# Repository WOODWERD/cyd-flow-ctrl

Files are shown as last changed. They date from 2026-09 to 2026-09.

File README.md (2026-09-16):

# Flow Ctrl — a push-to-talk button for Wispr Flow on the Cheap Yellow Display

_An open-hardware project from [WOODWERD LLC](https://woodwerd.com), a design group in Austin, Texas._

A dedicated desk button for [Wispr Flow](https://wisprflow.ai) dictation, built on the
ESP32-2432S028R "Cheap Yellow Display" (CYD). The board pairs with your Mac as a **Bluetooth
keyboard** and sends the same keyboard shortcut you already use — so there is nothing to install on
the computer, and nothing about your Wispr setup changes.

- **Hold to talk** — press and hold the big button, speak, let go: Wispr transcribes and pastes.
- **Hands-free** — tap once to lock in, talk for as long as you like, tap **STOP** to paste it all.
- **Send** — a Return key, so a dictated Claude prompt or chat message goes without touching the keyboard.
- **Discard** — sends `Esc` to throw the dictation away.
- **Transforms** — a second page fires Wispr's AI rewrites (Prompt Engineer, plus your own) on selected text.
- Printed split case with only USB-C exposed. STL/STEP included.

**New here?** [Build it](docs/BUILD.md) (parts, printing, inserts, assembly) then the [Getting Started guide](docs/GETTING_STARTED.md) (setup and every button, with annotated screens).

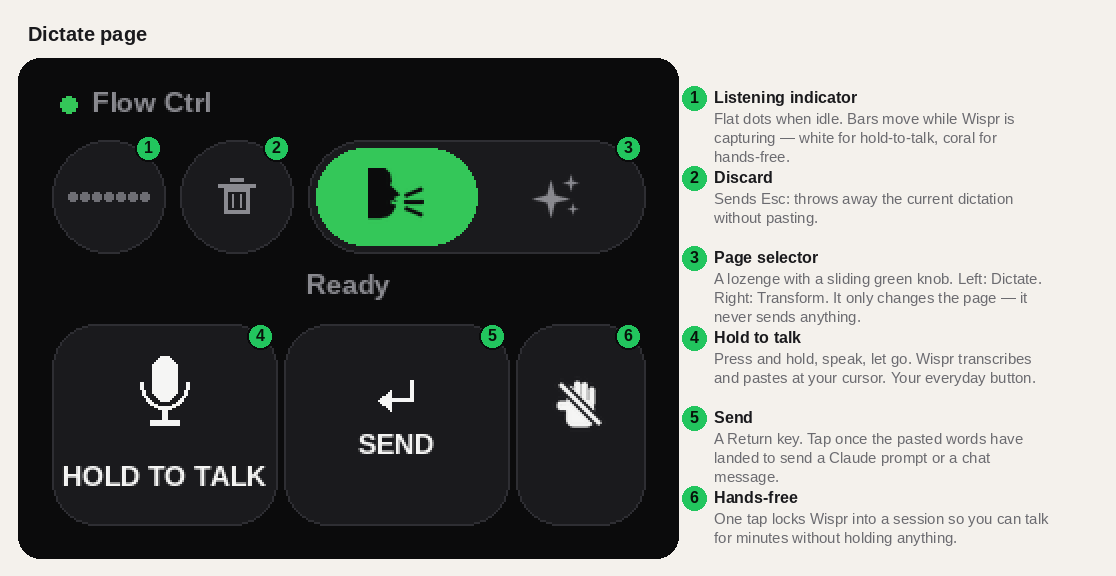
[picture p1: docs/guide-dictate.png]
Dictate page

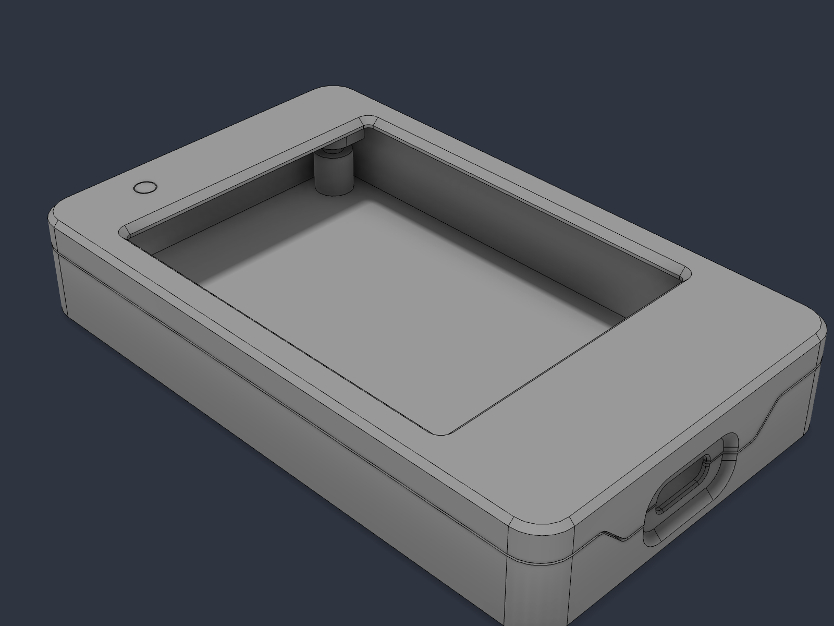
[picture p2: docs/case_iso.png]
Case


> Unofficial. Not affiliated with or endorsed by Wispr. See [THIRD_PARTY_NOTICES.md](THIRD_PARTY_NOTICES.md).

## How it works

Wispr Flow's push-to-talk is a keyboard shortcut. A MacBook's `Fn` key is not a real keycode, so no
external device can send it — but any chord with a normal modifier can be sent by a Bluetooth HID
keyboard, which is what the ESP32 pretends to be. The firmware ships with **Ctrl + Opt + T**; set
Wispr's *Push to talk* shortcut to that (Settings → General → Shortcuts), or rebuild with your own chord.

| On the screen | What the CYD sends | What Wispr does |
|---|---|---|
| **HOLD TO TALK** (press and hold) | chord held down for as long as your finger is | push-to-talk; release = transcribe & paste |
| **HANDS-FREE** (slashed-hand key, tap) | chord tapped twice, 120 ms apart | Wispr's "double-tap push-to-talk to lock" gesture → hands-free session |
| **STOP** (tap, while hands-free) | chord tapped once | ends the session, pastes |
| **STOP** (long-press) | nothing | resets the button's state only — use if you stopped Flow from the Mac |
| **SEND** | `Return` | sends what was just pasted — a Claude prompt, a chat message. Tap it once the words have landed |
| **Discard** (trash button in the top row) | `Esc` | discards the current dictation |
| **Page selector** (lozenge, top row) | nothing | slides between the Dictate and Transform pages |

There is no channel from Wispr back to the button, so the on-screen state is the button's best
guess. If they get out of sync, long-press STOP.

## Quick start (no toolchain)

1. **Flash.** Grab `release/flow-ctrl-v0.9.3-cyd2usb.bin` (USB-C / 2-USB board) or build the `cyd` env
   for the original micro-USB board. Either:
   - [ESP Web Tools / esptool-js](https://espressif.github.io/esptool-js/) in Chrome or Edge — 460800 baud, address `0x0`, or
   - `pip install esptool` then
     ```
     esptool.py --chip esp32 --port /dev/cu.usbserial-XXXX --baud 460800 write_flash 0x0 flow-ctrl-v0.9.3-cyd2usb.bin
     ```
   (Hold BOOT while plugging in if the port doesn't show up. 921600 baud is unreliable on the CH340.)
2. **Pair.** System Settings → Bluetooth → **"Flow Ctrl"**. The top-left dot turns green and the buttons
   enable. The bond is remembered and reconnects on power-up.
3. **Wispr Flow.** Settings → General → Shortcuts → *Push to talk* → press `Ctrl + Opt + T`.
   Wispr's hands-free lock follows the push-to-talk key automatically, so that's the only setting.
4. Talk.

If the chords do nothing in Terminal or a password field, that's macOS *Secure Keyboard Entry* — see
Wispr's help article on it. It affects every keyboard, not just this one.

## Page 2 — Transforms

The lozenge selector in the top row (talking head = Dictate, sparkles = Transform; a green knob slides to the active one) flips to a second page that fires Wispr's *Transforms* — AI rewrites
of whatever text is selected on the Mac. Buttons come from the `XFORMS` table at the top of `main.cpp`;
add a row, rebuild, and it appears in the next empty slot (four slots per page).

| Button | Sends | Set up in Wispr → Settings → Transforms |
|---|---|---|
| **PROMPT ENGINEER** | `Opt+2` | built in |
| **DRAWING NOTE** | `Opt+3` | custom: *Rewrite as terse construction-drawing callouts: material, size, finish, location. Fragments, not sentences. Uppercase. Keep dimensions exact.* |
| **CLIENT EMAIL** | `Opt+4` | custom: *Rewrite as a warm, concise client email from a residential designer. Plain language, no jargon. Keep every decision, dimension, price and date exact. End with one clear next step.* |
| **Select all** | `Cmd+A` | — |
| **View diff** | `Opt+O` | built in |

The Claude flow: dictate into the prompt box → **Select all** → **PROMPT ENGINEER** → back to **DICTATE** → **SEND**.
The top row — waveform circle, trash (Esc) and the page selector — is shared by both pages, so you can see a hands-free session running and discard it from either page. Switching is a tap, not a swipe, so a heavy finger on HOLD TO TALK can never turn into a page change.

## Docs

- [Build it](docs/BUILD.md) — bill of materials, which board to buy, printing, heat-set inserts, screws, assembly
- [Flash it](docs/flash/index.md) — one-click install from Chrome (on the docs site), or esptool
- [Getting Started](docs/GETTING_STARTED.md) — setup, every button and its intent, the three flows, troubleshooting
- [Case](case/README.md) — the printable files, print settings, tolerances
- [Firmware & code](docs/firmware.md) — build flags, code map, how to drive another app with it
- [Changelog](CHANGELOG.md)
- [Publishing checklist](docs/PUBLISHING.md) — how this reaches the CYD project list and the docs site

## Case

See [`case/README.md`](case/README.md): three parts, no supports, PETG, four M3 × 14 countersunk
screws and four M3 × 4 mm heat-set inserts. Only the USB-C port is exposed; a clear light pipe
carries the ambient-light sensor through the lid.

## License

Firmware, case and documentation: © 2026 WOODWERD LLC, released under MIT (see `LICENSE`). Third-party components and fonts retain their
own licences — listed in `THIRD_PARTY_NOTICES.md`.

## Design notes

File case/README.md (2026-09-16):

# Case — split PETG housing for the CYD (USB-C variant)

Three printed parts, four screws, four inserts. The step-by-step build (buying the board, inserts, assembly, with pictures) is in [`../docs/BUILD.md`](../docs/BUILD.md); the parts list as a spreadsheet is [`BOM.csv`](BOM.csv). Only the USB-C port is exposed; the light sensor gets a
clear light pipe so the firmware's ambient-light features still work behind a closed lid. Designed in
Fusion 360 by WOODWERD LLC; STL for printing, STEP if you want to modify it. This is housing **v2** — printed, test-fitted on a USB-C board, and the released design.

Case

| File | Part | Qty | Print |
|---|---|---|---|
| `CYD_FlowCtrl_Base.stl` | Base — board drops in USB-C end first, screws from below | 1 | open side **up**, no supports |
| `CYD_FlowCtrl_Lid.stl` | Lid — display window, insert bosses, USB-C tongue | 1 | face **down** on the bed, no supports |
| `CYD_FlowCtrl_LightPipe.stl` | Light pipe for the LDR — Ø2.9 rod on a Ø5 flange | 1 | **clear** filament, flange down, 100 % infill |

Outer size 54.6 × 90.6 × 16.1 mm. Wall 2.0 mm, 0.3 mm clearance per side around the board. Volumes:
base 15.2 cm³, lid 5.4 cm³.

## Print settings that matter
- **Material:** PETG recommended (heat-set inserts seat cleanly; PLA works at a lower iron temperature).
- **Layer height:** 0.2 mm (0.16 for a nicer display chamfer). 3–4 perimeters so the lip and groove are solid.
- **No supports** on any part. The USB-C funnel is a 45° loft and the port hole is bridged by the tongue.
- **Tolerances:** the lid rides on a 0.9 mm lip with 0.15 mm lateral clearance and a designed 0.3 mm
  parting-line gap outside. If your printer runs fat, a −0.1 mm horizontal expansion (XY compensation)
  on the lid is the first thing to try. If a USB-C cable won't click home, the local wall at the port
  is 0.8 mm — sand the lead-in chamfer before reprinting.
- **Test print first:** the base alone, and try a cable in it. That's the only fit that matters.

## Hardware (BOM)
| Qty | Part | Spec |
|---|---|---|
| 4 | M3 × 14 mm flat-head screw, 90° countersunk, hex socket | DIN 7991 / ISO 10642. Not M3 × 16 — the tip would reach the lid face. |
| 4 | M3 brass heat-set insert, **4 mm long**, OD 4.0–4.2 | The "M3 × L4" kit size (Voron M3×5×4 also fits). 5.7 mm inserts bottom out. |
| 1 | Cheap Yellow Display **USB-C / 2-USB** variant (ESP32-2432S028R with Type-C) | The micro-USB-only board also fits mechanically but its port is covered. |

Full fastener sheet with a section drawing: [`Fastener_Spec.pdf`](Fastener_Spec.pdf).

## Assembly
1. Heat-set the four inserts into the lid bosses — soldering iron with an M3 insert tip, ~230 °C for PETG
   (~200 °C for PLA), press to flush, let cool. Do this **before** the board goes in.
2. Push the light pipe up into its tube on the lid ceiling from inside, flange against the ceiling.
3. Flash the board first (it's easier with it out of the case), then drop it into the base, USB-C end first.
4. Lid on: tongue into the slot over the port, lip into the groove. Four screws from below, snug only — it's plastic.

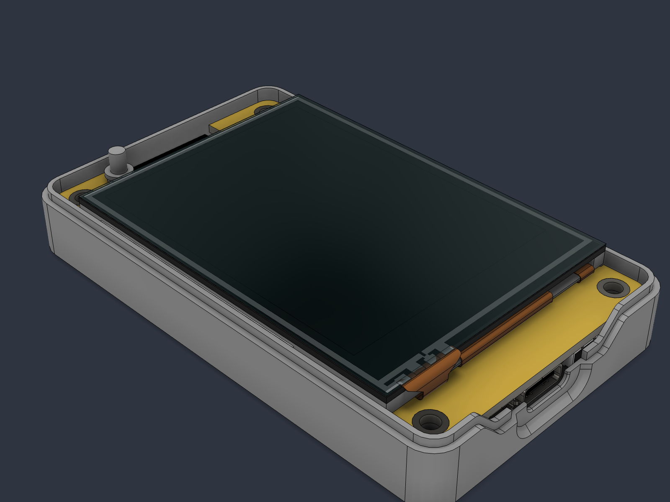
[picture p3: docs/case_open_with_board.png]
Board in base

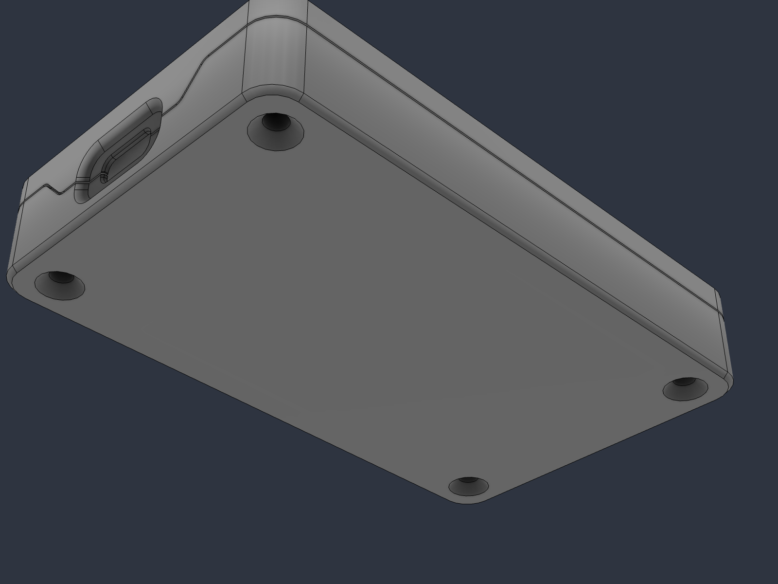
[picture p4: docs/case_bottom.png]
Underside


## What's covered / open
- Exposed: USB-C, light sensor (via pipe), display, touch.
- Covered: micro-USB, microSD, RST/BOOT buttons, JST headers, RGB LED (it may show through light-coloured filament).
  A flip-down SD door is the obvious next feature if you need the card slot.

## Modifying
`*.step` files are exact geometry. All corner radii are concentric with the board's R2.5 corners
(centres at ±22.5, ±40.5 mm from the board centre); the split is at z 2.5 mm above the PCB underside.

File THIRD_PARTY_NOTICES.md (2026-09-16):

# Third-party notices

Flow Ctrl itself is © 2026 WOODWERD LLC, MIT-licensed (see `LICENSE`). It is built on, and distributes, the following.

## Compiled into the firmware (`release/*.bin` and the PlatformIO build)

| Component | License | Notes |
|---|---|---|
| [LVGL](https://github.com/lvgl/lvgl) 9.5 | MIT | UI toolkit. `include/lv_conf.h` is derived from LVGL's template. |
| [TFT_eSPI](https://github.com/Bodmer/TFT_eSPI) | FreeBSD (BSD-2) + portions BSD from Adafruit_GFX | Display driver |
| [XPT2046_Touchscreen](https://github.com/PaulStoffregen/XPT2046_Touchscreen) | MIT | Touch controller |
| [NimBLE-Arduino](https://github.com/h2zero/NimBLE-Arduino) 2.x | Apache-2.0 (Apache NimBLE) | Bluetooth LE HID |
| [arduino-esp32](https://github.com/espressif/arduino-esp32) core | LGPL-2.1 | Arduino core for ESP32. Full source of this project is provided, satisfying relinking requirements. |
| [ESP-IDF](https://github.com/espressif/esp-idf) components (bundled by the platform) | Apache-2.0 | |
| [platform-espressif32](https://github.com/platformio/platform-espressif32) | Apache-2.0 | Build platform only; not distributed |

The BLE HID report map in `src/ble_kbd.cpp` follows the USB HID boot-keyboard layout published in the
USB HID Usage Tables (a public specification). The PnP ID values are the community-conventional ones
used by ESP32 BLE keyboard projects and do not claim a registered vendor ID.

## Fonts (`src/assets/*.c`, converted with `lv_font_conv`)

| Font | License | File |
|---|---|---|
| [Inter](https://github.com/rsms/inter) SemiBold 14/16/20 px | SIL Open Font License 1.1 | `src/assets/LICENSE-Inter-OFL.txt` |
| [IBM Plex Mono](https://github.com/IBM/plex) Medium 14 px | SIL Open Font License 1.1 | `src/assets/LICENSE-IBMPlex-OFL.txt` |

The `.c` files are bitmap conversions of subsets of these fonts, embedded in the firmware. Under the
OFL they are Modified Versions: they remain under the OFL, are not sold on their own, and the file
names use the original names only to identify their origin.

The UI icons (`src/assets/ic_*.c`, drawn by `tools/make_icons.py`) are original and MIT like the rest of the project.

## Hardware and CAD references

- The case was designed around the CYD board CAD model published in
  [witnessmenow/ESP32-Cheap-Yellow-Display](https://github.com/witnessmenow/ESP32-Cheap-Yellow-Display)
  (`3dModels/Havenview_CYD_CAD`), which is MIT-licensed. That model is **not** redistributed here —
  only the case bodies designed for it. Board pin assignments come from the same repository's `PINS.md`.
- USB-C opening dimensions follow the public USB Type-C Cable and Connector Specification, Appendix B.
- "Cheap Yellow Display" / CYD is a community nickname for the Sunton ESP32-2432S028 board; no Sunton
  documentation is redistributed.

## Trademarks

**Wispr Flow** is a trademark of Wispr AI, Inc. This project is an independent, unofficial accessory
that emulates a Bluetooth keyboard and sends ordinary keyboard shortcuts to the Wispr Flow app. It is
not affiliated with, endorsed by, or supported by Wispr. No Wispr artwork, logos, or code are used;
the on-screen waveform pill is an original drawing inspired by the app's listening indicator.
"Flow Ctrl" is used descriptively (a key that triggers Flow) and is not claimed as a brand.

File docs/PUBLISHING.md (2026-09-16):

# Publishing checklist

_Status: firmware v0.9.3 in daily use (v0.9 + the Bluetooth link fix); housing v2 printed, test-fitted and released as-is. Any later housing change: re-export `case/*.stl|step` and the renders from Fusion, rerun `tools/make_guide.py`, push._

This folder is a ready-to-push GitHub repository. Steps, in order.

## 1. The repo and the docs site
- Repo: **https://github.com/WOODWERD/cyd-flow-ctrl** (public; created 2026-09-16).
- Docs site: **https://woodwerd.github.io/cyd-flow-ctrl/** — built from `docs/` by `.github/workflows/pages.yml`
  (MkDocs Material) on every push to `main`. The workflow reuses the README as the home page, `case/README.md`
  as "The case" and the notices file, so there is one copy of every document. `docs/flash/` is an ESP Web Tools
  page that flashes `release/*.bin` from Chrome in one click.
- Settings → Pages → Source is **GitHub Actions** (set by hand 2026-09-16 — GitHub only allows it once the repo
  has content, and the workflow token can't set it).
- Day to day: edit, commit and push with GitHub Desktop (the folder is added there) or
  `git push` from a terminal. Each push rebuilds the site in about a minute; check the Actions tab if it doesn't.

Repo description: *Push-to-talk / hands-free button for Wispr Flow on the ESP32 Cheap Yellow Display, with a printed case.*
Topics worth adding: `esp32`, `cheap-yellow-display`, `cyd`, `wispr-flow`, `ble-hid`, `lvgl`, `3d-printing`.

## 2. Make a release
Tag the version (currently `v0.9.3`) and attach `release/flow-ctrl-v0.9.3-cyd2usb.bin` (and a `cyd` build if you make one) so people
can flash without cloning. Keep the file in `release/` too — the README links to it.

## 3. Add it to the CYD project list
The CYD repo lists community projects in `PROJECTS.md` and asks that you add your own by PR at the
bottom of the table (open source + functional are the only requirements). Fork
`witnessmenow/ESP32-Cheap-Yellow-Display`, append this row, open the PR:

```
| Flow Ctrl | Push-to-talk / hands-free button for Wispr Flow dictation — the CYD pairs as a Bluetooth keyboard; includes a printed case | WOODWERD LLC | None | [Github](https://github.com/WOODWERD/cyd-flow-ctrl) | |
```

Adjust the column order to whatever the table has when you get there (Name · Description · Author ·
Additional Hardware? · Project Page · WebFlash). The case can also be offered as a line under
"Other cases from elsewhere" in `3dModels/README.md` pointing at `case/`, if you'd like it findable
from there too — that list already links out to Printables/MakerWorld/GitHub.

## 4. Optional: web flasher
The CYD list has a WebFlash column. A GitHub Pages site with ESP Web Tools and a `manifest.json`
pointing at the merged bin is an afternoon's work and lets people flash from Chrome with one click;
the Feeder-panel-style `esptool-js` route works but needs the user to type the address.

## 5. Optional: Printables / MakerWorld
Upload `case/*.stl` with the three renders in `docs/` and the text of `case/README.md`. Link back to
the repo for firmware. License choice there: CC-BY-4.0 is the usual pick for models (MIT is fine
too; just be consistent with the repo).

## Before pushing — things checked already
- No personal paths, serial-port names, or unrelated project references in the tree.
- Getting Started / Build guides and their images regenerate from `tools/make_guide.py` — rerun after any screen change so the pictures match the firmware.
- Fonts carry their OFL licence files; third-party libraries listed with licences.
- Wispr trademark disclaimer present; no Wispr artwork or code included.
- CYD board CAD (MIT) is referenced, not redistributed.
- BLE manufacturer string is "WOODWERD LLC", matching the LICENSE and README attribution.

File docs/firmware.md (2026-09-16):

# Firmware & code

## Build it yourself

```
pip install platformio
pio run -e cyd2usb          # USB-C / 2-USB board (ST7789, BGR)
pio run -e cyd              # original micro-USB board (ILI9341)
tools/merge.sh cyd2usb v0.9.3 # single 0x0 image from the build
```

Build flags (add to `build_flags` or `-D` on the command line):

| Flag | Default | Meaning |
|---|---|---|
| `PTT_MODS` | `(MOD_CTRL\|MOD_OPT)` | modifier bits of your Wispr push-to-talk chord (`MOD_CTRL`, `MOD_SHIFT`, `MOD_OPT`, `MOD_CMD`) |
| `PTT_KEY` | `KEY_T` | the key in the chord (`KEY_T`, `KEY_SPACE`, or any HID usage code) |
| `PANEL_ROTATION` | `1` | `3` flips the landscape image 180° (USB on the other side) |
| `BLE_NAME` | `"Flow Ctrl"` | name shown in Bluetooth settings |
| `DIM_AFTER_MS` | `0` | `0` = always full brightness (the board is USB-powered). Set e.g. `45000` to dim after idle; it never turns off |
| `LED_QUIET` | unset | define to silence the RGB LED |
| `TOUCH_DEBUG` | unset | print raw touch coordinates on serial |

Stack: PlatformIO · espressif32 7.1.3 (Arduino) · LVGL 9.5 · TFT_eSPI · XPT2046_Touchscreen ·
NimBLE-Arduino 2.x. ~103 KB RAM, ~890 KB flash. Compiles clean with no PSRAM.

## The screen

Landscape 320 × 240. The visual cue is Wispr's own listening indicator: a dark circle with a row of
bars that lie flat as dots when idle and breathe while you're talking — white for push-to-talk,
coral when locked into hands-free. The rim of the circle and the RGB LED follow the same state.
Buttons are big because you'll hit them without looking: HOLD TO TALK and SEND are equal at 112 × 100 px,
with a 64 px hands-free key (a slashed-hand icon) on the right. Start hands-free and the row re-flows —
HOLD TO TALK slides off, SEND slides left, and a big coral STOP fills the rest until you tap it. The backlight stays at full brightness — the board is USB-powered,
so there is nothing to save and never a "wake-up" tap.

Colours, radii and fonts are tokens in `src/theme.h`. `tools/mock.py` renders every state with PIL so
you can retune without flashing; `tools/make_guide.py` builds the annotated screens in `docs/`.

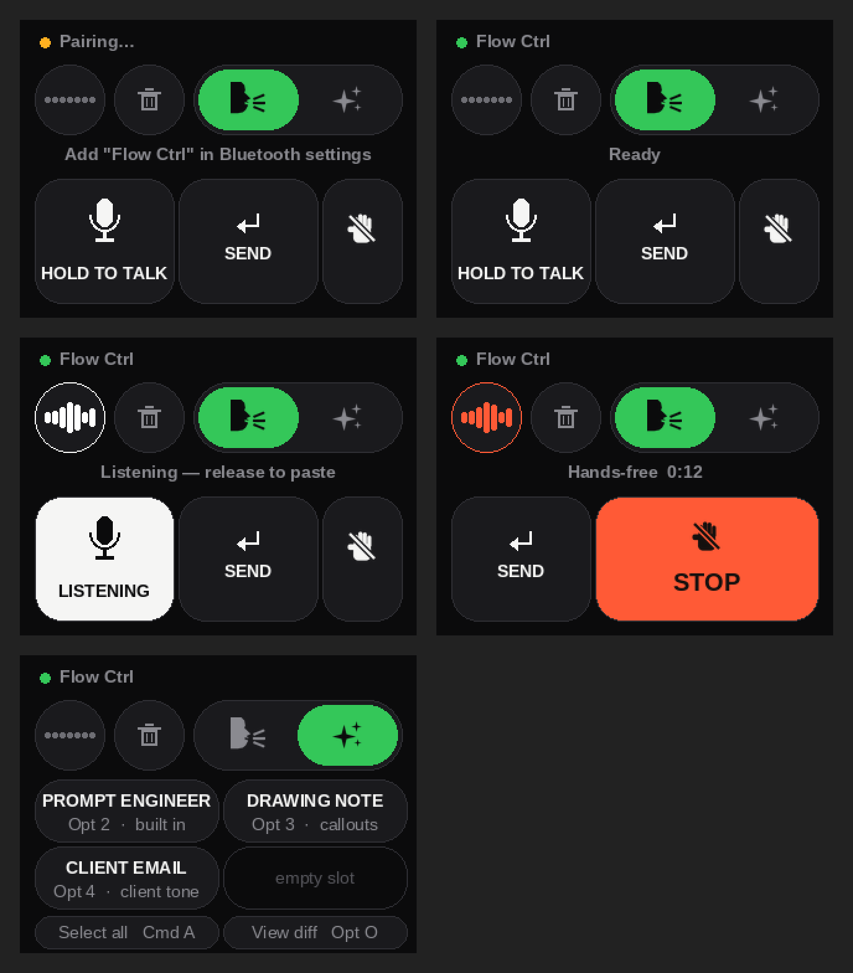
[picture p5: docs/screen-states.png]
All states


## Code map

```
platformio.ini      two envs: cyd (ILI9341) / cyd2usb (ST7789, BGR). Pins from the CYD repo's PINS.md
src/main.cpp        UI (LVGL), touch, state machine, backlight, LED
src/ble_kbd.*       minimal NimBLE HID keyboard: boot-keyboard report map, press / releaseAll / tap
src/theme.h         colour, radius and font tokens
src/assets/         Inter SemiBold 14/16/20 + IBM Plex Mono 14 as LVGL fonts (OFL, licences alongside); ic_*.c icons (head, sparkles, hand)
include/lv_conf.h   LVGL 9.5 configuration
tools/merge.sh      bootloader + partitions + boot_app0 + app → one image at 0x0
tools/make_icons.py PIL-drawn icons → LVGL A8 arrays in src/assets (needs LVGL's LVGLImage.py)
tools/mock.py       PIL mock of the screen states → flow-ctrl-mock.png (copied to docs/screen-states.png)
tools/make_guide.py annotated screens + flow strip for docs/GETTING_STARTED.md
case/               STL + STEP for base, lid, light pipe; print/assembly notes; fastener spec
release/            prebuilt merged image
```

### Notes for anyone adapting it
- The display is driven with a plain TFT_eSPI flush callback and `setRotation(1)`, not LVGL's
  `lv_tft_espi` helper, so landscape needs no software rotation.
- Touch calibration is self-adjusting: the raw min/max grow as you use it, so the corners get
  accurate after a few presses. `TOUCH_DEBUG` shows the raw numbers if a board is far off.
- The HID layer sends modifiers in one report and the key in the next, 12 ms later, like a physical
  keyboard does — some apps ignore a chord that arrives in a single report.
- **Bluetooth link tuning (v0.9.3).** macOS opens a HID link with a 720 ms supervision timeout, then
  moves a bonded keyboard to *interval 15 ms, latency 22*. On the ESP32 that latency is the problem:
  the board is allowed to sleep through 22 connection events, occasionally misses a channel-map
  instant, and the Mac drops the link with `0x228` — which looked like the button "going back into
  pairing mode" every minute or two. `ble_kbd.cpp` therefore waits until the link is encrypted, then
  asks for **latency 0, 6 s timeout** (`BleKbd::tick()` from `loop()`), and asks again if the Mac
  re-applies latency (three tries per connection, so it can never ping-pong). The board is
  USB-powered, so listening on every event costs nothing. The serial log at 115200 prints every
  parameter change and decodes disconnect reasons if you need to see it on your own Mac.
- Any other app with a keyboard shortcut (Superwhisper, MacWhisper, a meeting mute key, a macro)
  can be driven the same way: change `PTT_MODS` / `PTT_KEY`.

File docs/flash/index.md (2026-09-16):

# Flash it

The quickest way to put Flow Ctrl on a board: plug it in, open this page in **Chrome or Edge**
(Web Serial — Safari and Firefox can't), press the button, pick the port.

<script type="module" src="https://unpkg.com/esp-web-tools@10/dist/web/install-button.js?module"></script>
<esp-web-install-button manifest="manifest.json">
  <span slot="unsupported">This browser can't talk to serial ports — use Chrome or Edge.</span>
  <span slot="not-allowed">Serial access is blocked here (needs HTTPS).</span>
</esp-web-install-button>

!!! note "Which board"
    The prebuilt image is for the **USB-C / 2-USB** Cheap Yellow Display (ST7789 panel). The original
    micro-USB board needs the `cyd` build — see [Firmware & code](../firmware.md).

If the port doesn't appear, hold **BOOT** on the board while plugging it in, then try again. Some
boards need a USB-C → USB-A cable rather than C-to-C.

## From a terminal instead

```
pip install esptool
esptool.py --chip esp32 --port /dev/cu.usbserial-XXXX --baud 460800 write_flash 0x0 flow-ctrl-v0.9.3-cyd2usb.bin
```

The image is in the repo under `release/`, and attached to each GitHub release.

## Then

Pair it and set the one Wispr shortcut — [Getting started](../GETTING_STARTED.md#1-set-up-once).

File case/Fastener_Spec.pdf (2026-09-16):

# CYD Housing v2 — Fastener Spec

ESP32-2432S028 split housing · Fusion file CYD_Housing_Split_v2 · 4 corners, all identical · 2026-09-15 BUY / PULL FROM THE BIN

Qty | Part | Spec

### 4 M3 × 14 mm flat-head screw

90° countersunk, hex socket

DIN 7991 / ISO 10642. Thread Ø 3.0 (measures 2.9–3.0). Head Ø 5.5– 6.0, head height ≈1.65. 2 mm hex key. Length 14 is measured including the head. Stainless or black oxide, either is fine.

### 4 M3 heat-set threaded insert

brass, knurled

Length 4.0 mm, outside Ø 4.0–4.2 (the “M3 × L4” size in most kits; Voron-style M3×5×4 also fits). Do not use the 5.7 mm-long ones — they bottom out in the boss.

WHICH SCREWS IN THE BIN ARE M3?

| M3 | M4 | M5
Thread Ø (calipers) | 2.9–
| 3.0 | 3.9–
| | 4.0 | 4.9–
| | | 5.0
Flat head Ø | 5.5–
| 6.0 | ~8.0 | ~10.0
Hex key (flat head) | 2.0 | 2.5 | 3.0
Drops through the CYD’s Ø3 board hole? | Yes | No | No

Fastest test: hold the bare board over the bin — the screw that falls through a mounting hole is M3.

HOLES IN THE PRINT (ALREADY MODELLED)

Where | Feature
Lid boss (×4) | Ø4.0 × 5.0 deep, insert pressed to flush with the boss face
Base underside (×4) | Ø3.2 through, 90° countersink Ø6.4 at the surface
Board | Ø3.0 at (±21, ±39) — screw is a clearance fit

Insert install: soldering iron with an M3 insert tip (or a clean conical tip), ~230 °C for PETG / ~200 °C for PLA. Start the insert straight, let the iron’s weight do the work, stop flush, hold 5 s, let cool before threading anything in. Do this before the board goes in.

SECTION THROUGH ONE CORNER (SCALE 12 PX = 1 MM)

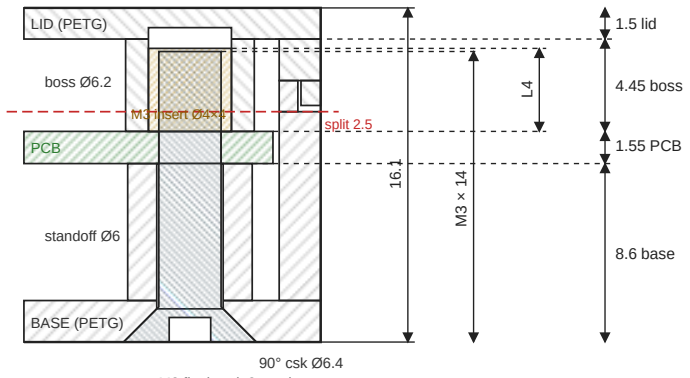
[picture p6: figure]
split 2.5; 8.6 base; 1.55 PCB; 4.45 boss; LID (PETG); 1.5 lid; PCB; BASE (PETG); standoff Ø6; boss Ø6.2; M3 insert Ø4×4; 90° csk Ø6.4

M3 flat head, 2 mm hex

Numbers that matter
Thread in insert: ≈3.9 mm (tip at z 5.4, insert 1.55–5.55)
Tip to lid face: 2.1 mm — do not substitute M3 × 16
Torque: snug with the short arm of the key. It's plastic.
Seam: lid bears on the lip top; 0.3 mm parting gap at the skin

Assembly order
1. Heat-set the 4 inserts into the lid bosses
2. Push the light pipe up into its tube from inside
3. Drop the board into the base, USB-C end first
4. Lid on — lip into groove — 4 × M3 × 14 from below

Print
Base open side up · Lid face down · Light pipe flange down, clear, 100%

Section through the hole axis at one corner (all four identical). Red dash = split line z 2.5; 16.1 = overall height; L4 = insert length. Hatching: grey = printed PETG, green = PCB, gold = brass insert, blue = steel screw. Dimensions in mm.

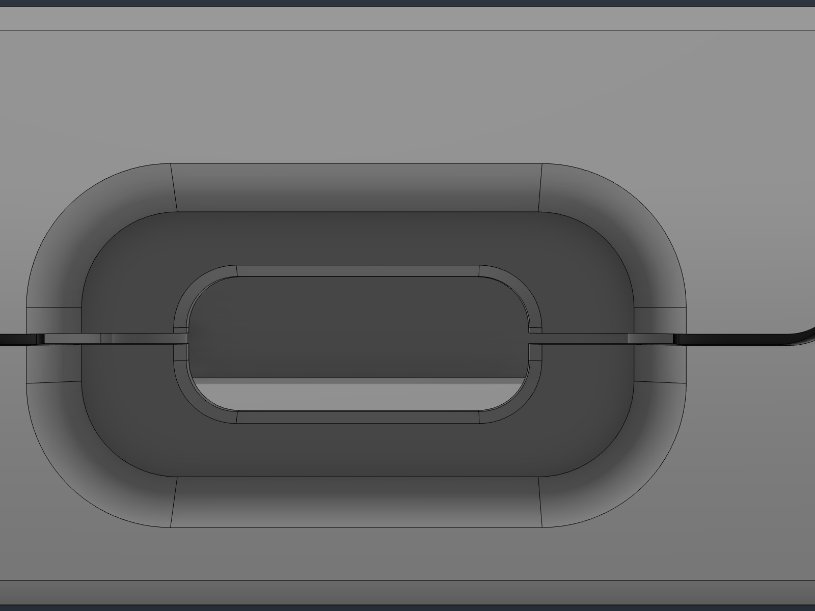
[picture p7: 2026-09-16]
docs/case_front_usb.png

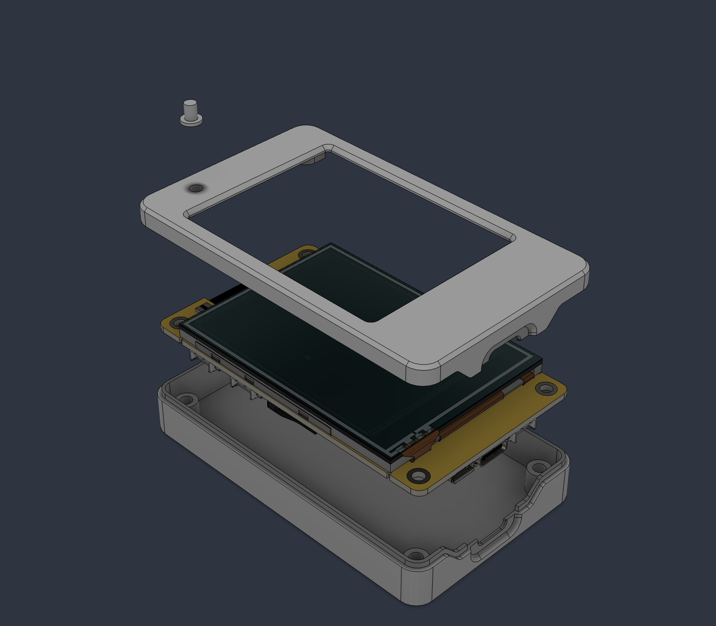
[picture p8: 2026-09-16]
docs/case_exploded.png

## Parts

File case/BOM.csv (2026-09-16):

Item | Qty | Part | Specification | Notes
1 | 1 | Cheap Yellow Display board | ESP32-2432S028R, 2.8in 320x240 resistive touch, USB-C (2-USB / CYD2USB) variant | Must be the version with a USB-C port; the case only exposes USB-C
2 | 1 | USB-C cable (data) | USB-C to USB-A recommended | Some CYD boards lack CC resistors; C-to-C into a Mac C port may not power up
3 | 4 | Flat-head screw | M3 x 14 mm, 90 deg countersunk, hex socket, DIN 7991 / ISO 10642 | Length includes the head. Do not use M3 x 16. 2 mm hex key
4 | 4 | Heat-set threaded insert | M3, brass, knurled, 4.0 mm long, OD 4.0-4.2 mm | The M3 x L4 kit size; Voron M3x5x4 also fits. Not the 5.7 mm ones
5 | 1 | Printed part: Base | CYD_FlowCtrl_Base.stl, PETG, 0.2 mm, 3-4 perimeters, no supports | Print open side up
6 | 1 | Printed part: Lid | CYD_FlowCtrl_Lid.stl, PETG, 0.2 mm, 3-4 perimeters, no supports | Print face down
7 | 1 | Printed part: Light pipe | CYD_FlowCtrl_LightPipe.stl, clear filament, 100% infill | Print flange down
8 | 1 | Tool: soldering iron | With an M3 insert tip, or a clean conical tip | ~230 C for PETG, ~200 C for PLA
9 | 1 | Tool: hex key | 2 mm | For the four screws

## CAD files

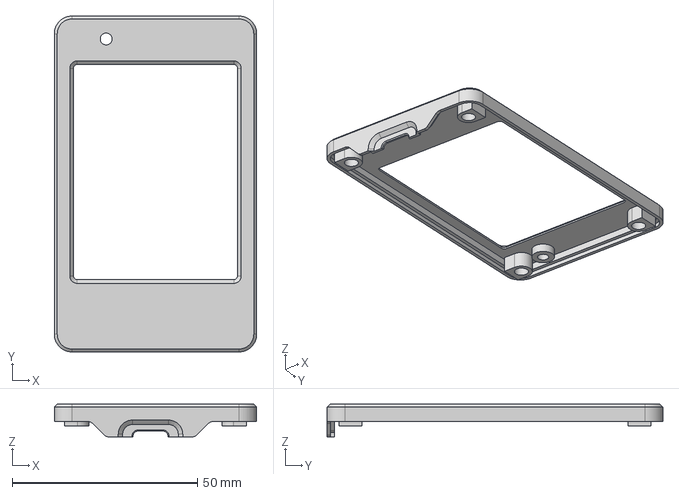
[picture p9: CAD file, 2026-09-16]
case/CYD_FlowCtrl_Lid.step
54.6 x 90.6 x 8.80 mm

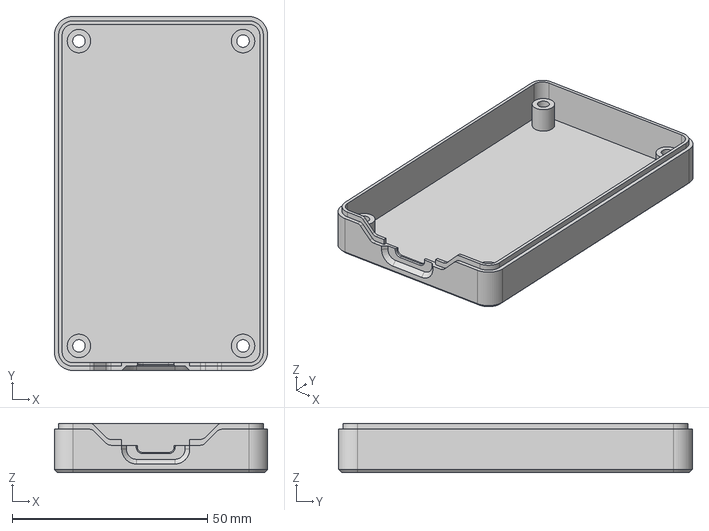
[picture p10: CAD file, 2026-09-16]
case/CYD_FlowCtrl_Base.step
54.6 x 90.6 x 12.6 mm

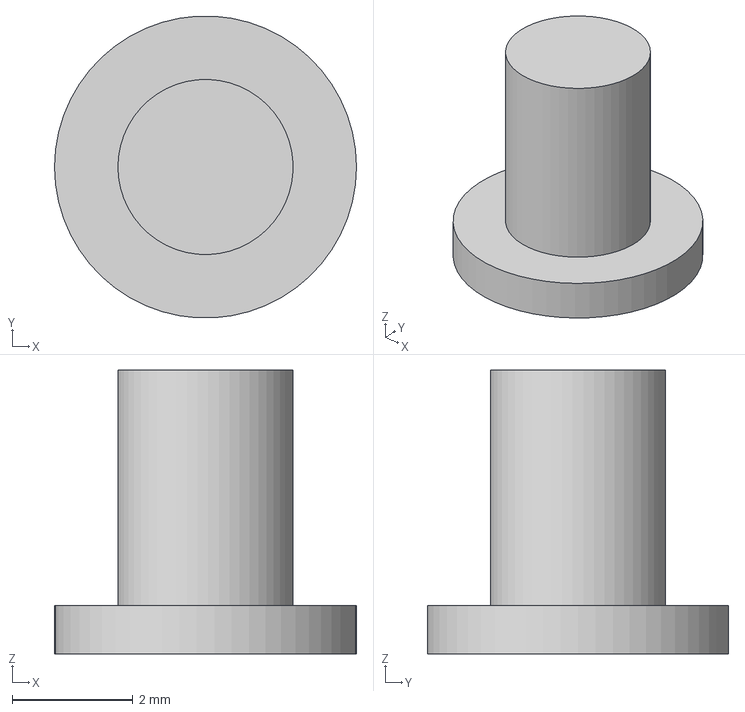
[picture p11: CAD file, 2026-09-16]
case/CYD_FlowCtrl_LightPipe.step
5.00 x 4.99 x 4.70 mm

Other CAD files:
case/CYD_FlowCtrl_Base.stl
case/CYD_FlowCtrl_Lid.stl
case/CYD_FlowCtrl_LightPipe.stl

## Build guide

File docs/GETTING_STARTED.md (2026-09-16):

# Getting started with Flow Ctrl

Flow Ctrl is a desk button for [Wispr Flow](https://wisprflow.ai) dictation. It is a Cheap Yellow Display
(an ESP32 with a 2.8" touchscreen) in a printed case that pairs with your Mac as a Bluetooth keyboard.
Every button on it just sends a keyboard shortcut Wispr already understands — so there is nothing to
install on the Mac, and if you unplug it, nothing changes.

This guide assumes the puck is built. If you are starting from parts, [BUILD.md](BUILD.md) comes first —
board, printing, inserts, screws. This is the ten-minute version of what follows: what to set up once,
then what each button is for.

## 1 · Set up once

**Flash the firmware.** Plug the board in over USB-C and either use the web flasher in Chrome
([esptool-js](https://espressif.github.io/esptool-js/): 460800 baud, address `0x0`,
file `release/flow-ctrl-v0.9.3-cyd2usb.bin`) or, from a terminal:

```
pip install esptool
esptool.py --chip esp32 --port /dev/cu.usbserial-XXXX --baud 460800 write_flash 0x0 flow-ctrl-v0.9.3-cyd2usb.bin
```

The screen comes up with an amber dot and "Pairing…".

**Pair it.** System Settings → Bluetooth → **Flow Ctrl** → Connect. The dot turns green, the title
reads "Flow Ctrl", and the buttons wake up. The Mac remembers it; from now on it reconnects on its own
whenever the board is powered.

**Point Wispr at it.** Wispr Flow → Settings → General → Shortcuts → *Push to talk* → press
**Ctrl + Opt + T**. That is the only setting Flow Ctrl needs. (If you would rather keep a different
chord, the firmware's chord is a build flag — see the README.)

**Optional — Transforms.** If you want the second page, Wispr Flow → Settings → Transforms → create
two custom transforms and give them the shortcuts **Opt + 3** and **Opt + 4**. Suggested prompts are
in the README. Prompt Engineer is built in and needs nothing.

Then put it where your hand rests when you are not typing. It is always on, always full brightness,
and never sleeps — a button you have to wake up first is not a button.

## 2 · The Dictate page

Dictate page

This is the page it wakes up on and the one you will live on.

1. **Listening indicator.** The circle shows what Wispr is doing. Flat dots: idle. White bars: you are
   holding to talk. Coral bars: a hands-free session is running. It is on both pages, so you can
   never lose track of an open session.
2. **Discard.** Sends `Esc`. Wispr throws away whatever it is currently transcribing and pastes
   nothing. Use it when you said the wrong thing.
3. **Page selector.** A lozenge with a green knob that slides between two icons — the talking head
   (Dictate) and the sparkles (Transform). It only changes what the screen shows. It never sends a key.
4. **Hold to talk.** The everyday button. Press and keep your finger down, say a sentence or two, let
   go. Wispr transcribes and pastes at wherever your cursor is. Feels like a walkie-talkie.
5. **Send.** A Return key. When you dictate into a chat box or a Claude prompt, tap this once the
   words have appeared and it goes. It is a separate key on purpose: Wispr pastes a beat *after*
   you let go, and a Return fired too early would send an empty message.
6. **Hands-free.** The slashed-hand key. One tap starts a session that runs until you stop it — for
   long dictation where holding a button for three minutes would be silly.

## 3 · Hands-free, while it runs

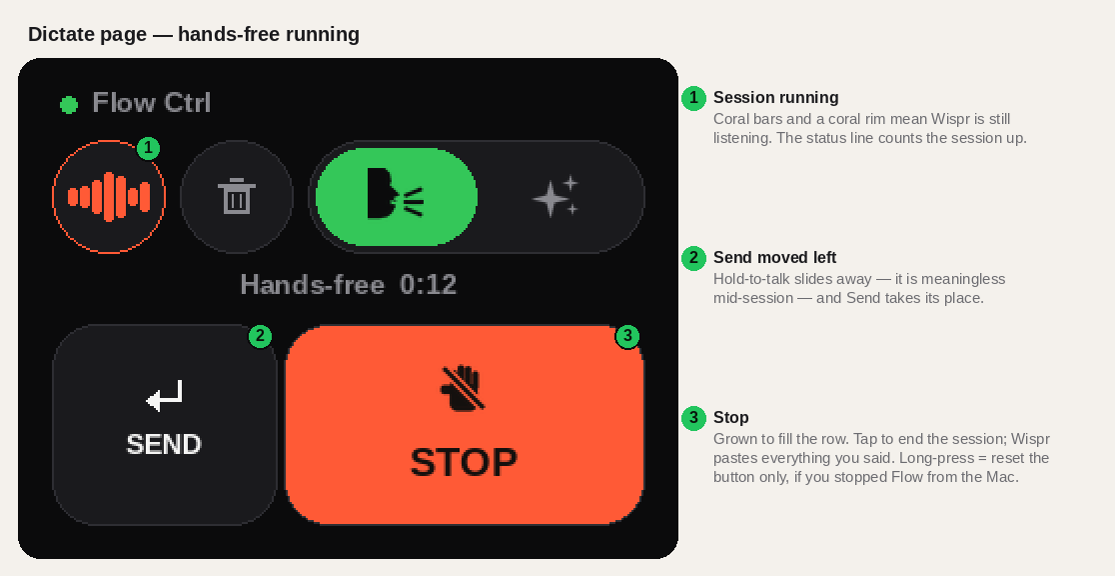
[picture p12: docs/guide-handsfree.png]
Hands-free running


Tap the hand and the row re-arranges itself. Hold-to-talk slides off the screen (it is meaningless
mid-session), Send slides into its place, and a large coral **STOP** fills the rest of the row. The
status line counts the session up.

- Talk. Pause. Think. Nothing times out on the button's side.
- **STOP** ends the session; Wispr transcribes and pastes everything you said as one block. The row
  slides back to normal.
- **Discard** (the trash) cancels the session without pasting.
- If you stopped Wispr from the Mac instead — clicked its bar, hit Esc on the keyboard — the button
  does not know, because nothing flows back from the Mac to it. **Long-press STOP** to reset the
  button without sending anything.

## 4 · The Transform page

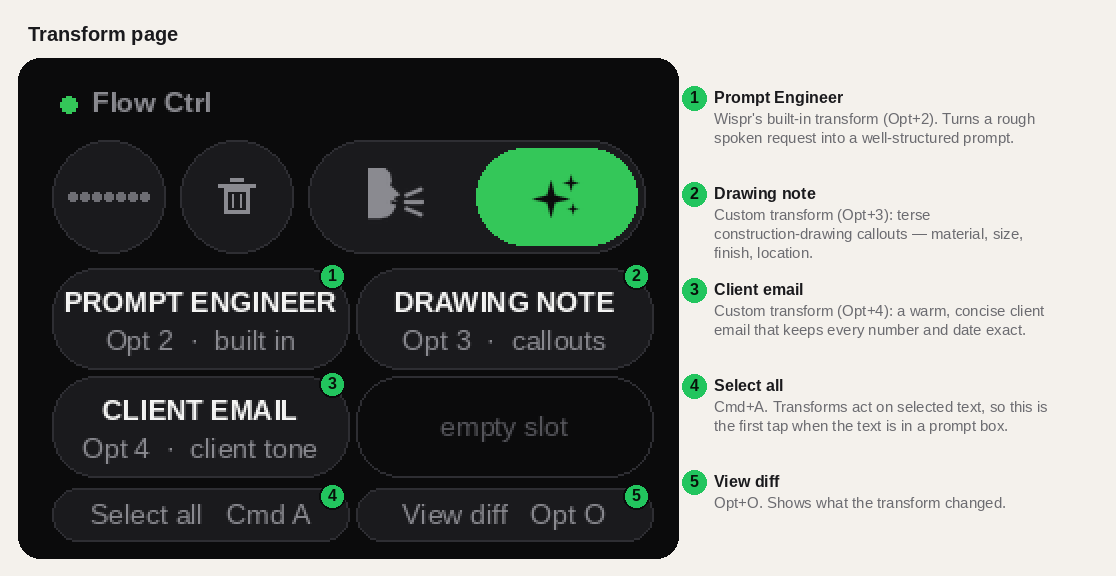
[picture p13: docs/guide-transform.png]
Transform page


Wispr *Transforms* rewrite text you have selected on the Mac. The page fires them; it does not know
what is selected, so the order is always **select, then tap**.

1. **Prompt Engineer** — Wispr's built-in transform. Turns a rough spoken request into a
   well-structured prompt. This is the one that makes Flow Ctrl useful with Claude.
2. **Drawing note** — custom. Rewrites what you said as terse construction-drawing callouts:
   material, size, finish, location. Fragments, uppercase, dimensions untouched.
3. **Client email** — custom. Turns a spoken rough draft into a warm, concise client email that
   keeps every decision, dimension, price and date exactly as you said them.
4. **Select all** — `Cmd+A`. When you have just dictated into a prompt box, this selects it so the
   next tap has something to transform.
5. **View diff** — `Opt+O`. Shows what the transform changed.

The fourth slot is empty on purpose; a transform earns a button when you notice you reach for it every
day. Adding one is a line in `src/main.cpp`.

## 5 · Three flows you will use

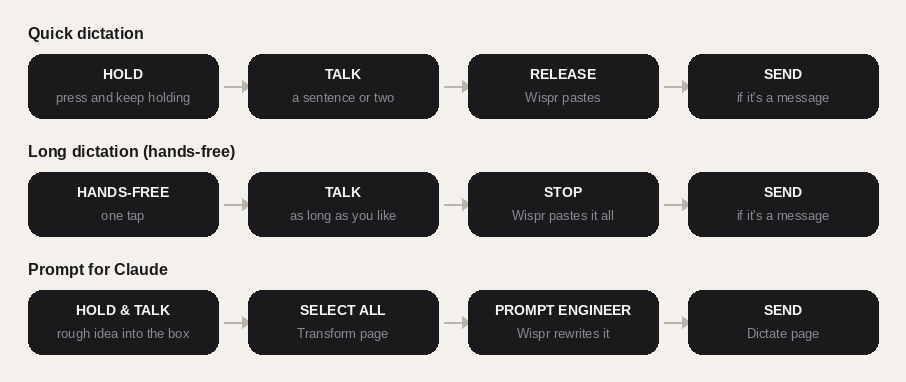
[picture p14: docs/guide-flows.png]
Flows


**Quick dictation.** Hold → talk → release → (Send, if it is a message). Most of the day is this.

**Long dictation.** Hands-free → talk as long as you like → Stop → Send. For a brief, a design
rationale, a long reply. Everything arrives as one paste, so check the length limit of wherever it
is landing before you dictate an essay into it.

**A prompt for Claude.** Hold and talk your rough idea straight into the prompt box → slide to
Transform → **Select all** → **Prompt Engineer** → slide back → **Send**. Four taps and the thing
Claude receives is better than what you said.

## 6 · When something does not work

| Symptom | Likely cause |
|---|---|
| Amber dot, "Pairing…" | Not connected. Pair in Bluetooth settings; if it was paired before, toggle Bluetooth on the Mac. |
| Keeps dropping back to "Pairing…" every minute or two | Firmware older than v0.9.3. Reflash — see [Firmware & code](firmware.md#notes-for-anyone-adapting-it) for what changed. |
| Green dot, but nothing happens | Wispr's push-to-talk shortcut is not `Ctrl+Opt+T`, or Wispr is not running. |
| Works everywhere except Terminal / a password field | macOS *Secure Keyboard Entry* blocks Wispr there for every keyboard. Not a Flow Ctrl problem. |
| Hands-free starts but a tap of STOP does not paste | Wispr missed the double-tap that starts the lock. Try again; if it is consistent, the tap gap is a constant in `src/main.cpp`. |
| Screen shows STOP but Wispr is idle | You stopped it from the Mac. Long-press STOP. |
| Taps land off-target | The touch panel self-calibrates as you use it; a few presses toward each corner settles it. |

## 7 · Where to go next

- The [README](../README.md) has the build flags, the code map, and the chord table.
- [BUILD.md](BUILD.md) has the parts list, printing, inserts and assembly; [`case/README.md`](../case/README.md) the printable files and tolerances.
- Any other app with a keyboard shortcut can be driven the same way — change two constants.

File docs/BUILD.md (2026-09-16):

# Build it — parts, printing, inserts, assembly

Everything between "I'd like one" and "it's on my desk." Nothing here needs soldering beyond a
soldering iron used as a heat source for the inserts. Budget an evening: an hour of printing you
don't have to watch, twenty minutes at the bench.

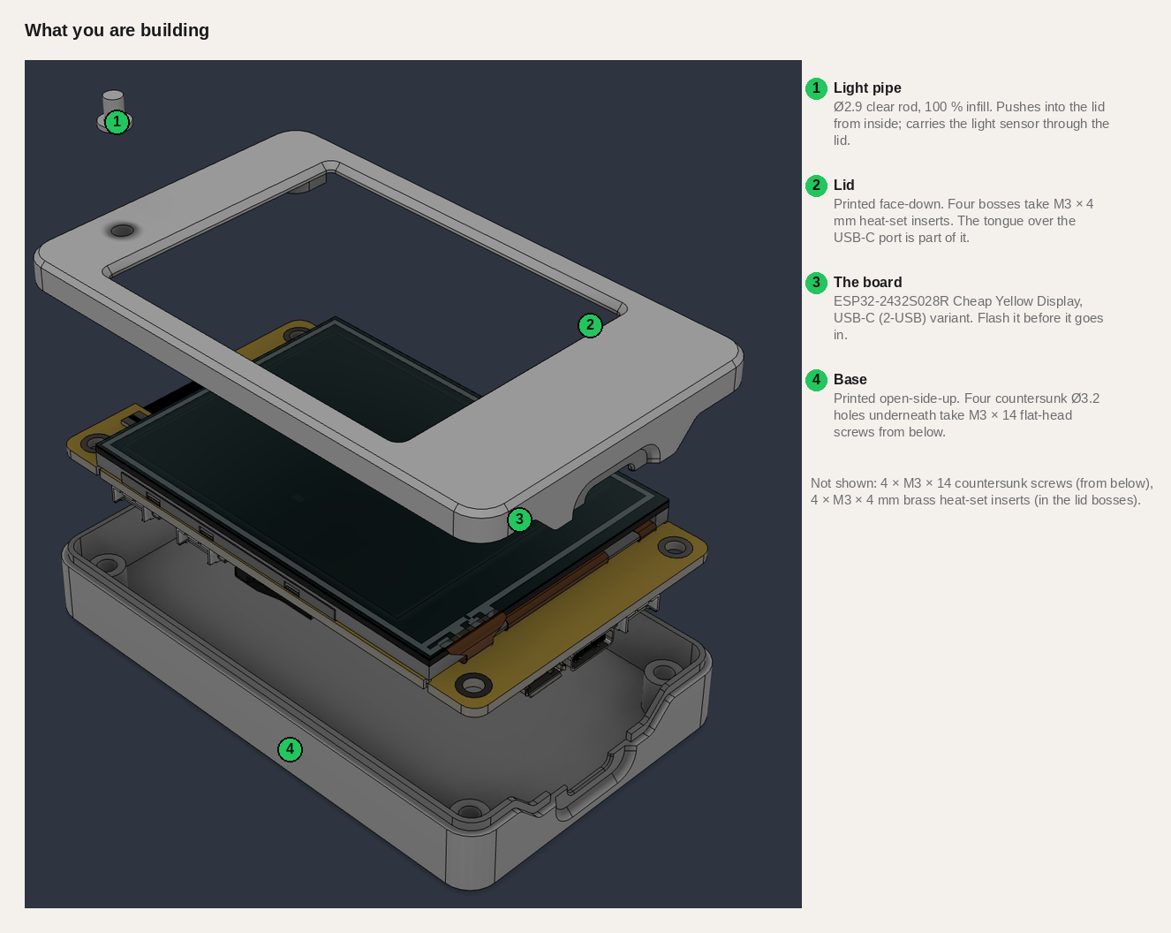
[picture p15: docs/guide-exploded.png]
Exploded


## Bill of materials

| # | Qty | Part | Spec | Notes |
|---|---|---|---|---|
| 1 | 1 | **Cheap Yellow Display board** | ESP32-2432S028R, 2.8" 320 × 240 touch, **USB-C (2-USB) variant** | The case only exposes USB-C — buy the version that has a USB-C port |
| 2 | 1 | USB-C cable, data | USB-C → USB-A recommended | Some boards lack CC resistors; C-to-C into a Mac's C port may not power |
| 3 | 4 | **Flat-head screw** | **M3 × 14 mm**, 90° countersunk, hex socket, DIN 7991 / ISO 10642 | Length includes the head. Not M3 × 16. 2 mm hex key |
| 4 | 4 | **Heat-set threaded insert** | **M3, brass, 4 mm long, OD 4.0–4.2 mm** | The "M3 × L4" kit size; Voron M3×5×4 also fits. Not the 5.7 mm ones |
| 5 | 1 | Printed: **Base** | `CYD_FlowCtrl_Base.stl`, PETG, no supports | open side up |
| 6 | 1 | Printed: **Lid** | `CYD_FlowCtrl_Lid.stl`, PETG, no supports | face down |
| 7 | 1 | Printed: **Light pipe** | `CYD_FlowCtrl_LightPipe.stl`, **clear** filament, 100 % infill | flange down |
| — | — | Tools | soldering iron (insert tip or clean conical), 2 mm hex key, 3D printer | |

Same list as a spreadsheet: [`../case/BOM.csv`](../case/BOM.csv). Fastener detail with a section
drawing: [`../case/Fastener_Spec.pdf`](../case/Fastener_Spec.pdf).

Build order

## 1 · Buy

| Qty | Part | What to look for | Where |
|---|---|---|---|
| 1 | **ESP32-2432S028R "Cheap Yellow Display", USB-C variant** | 2.8" 320 × 240 touch display with an ESP32 on the back. Listings say *ESP32-2432S028R*, *CYD*, or *Cheap Yellow Display*. **Get the version with a USB-C port** (it has both micro-USB and USB-C on the board; the community calls it "CYD2USB" or "2-USB"). The case only exposes USB-C. | Amazon, AliExpress, Banggood — usually well under $20. Two-packs are common. |
| 1 | USB-C cable, data-capable | Any phone cable that syncs data works. Some CYD boards lack the CC resistors, so a **USB-C → USB-A** cable into an A port (or an A adapter) is the reliable choice; C-to-C into a Mac's C port sometimes gives no power. | you have one |
| 4 | **M3 × 14 mm flat-head screw**, 90° countersunk, hex socket | DIN 7991 / ISO 10642. Stainless or black oxide. Length **14** including the head — **not 16**, the tip would reach the lid face. 2 mm hex key. | any metric fastener kit or hardware store |
| 4 | **M3 brass heat-set insert, 4 mm long, OD 4.0–4.2 mm** | The "M3 × L4" size in most insert kits; Voron-style M3×5×4 also fits. **Not the 5.7 mm ones** — they bottom out in the boss. | insert kit, CNC Kitchen, Amazon |
| ~30 g | Filament, PETG recommended | Base and lid. PLA works (use a cooler iron for the inserts). | — |
| a scrap | **Clear** filament | For the light pipe. Transparent PETG or clear PLA. Natural/translucent works; opaque does not. | — |

**Tools:** a 3D printer (0.4 mm nozzle is fine) · a soldering iron, ideally with an M3 insert tip, a
clean conical tip will do · a 2 mm hex key · optional calipers for sorting screws.

**Is this screw M3?** Hold the bare board over the bin: the screw that drops through a corner hole is
M3 (Ø3.0 thread, 5.5–6 mm head). M4 and M5 won't pass. The fastener sheet has a sorting table:
[`../case/Fastener_Spec.pdf`](../case/Fastener_Spec.pdf).

## 2 · Print

Files in [`../case/`](../case/). STL for slicing, STEP if you want to change something.

| File | Orientation | Notes |
|---|---|---|
| `CYD_FlowCtrl_Base.stl` | **open side up** | no supports; the countersinks are on the bed side and print clean |
| `CYD_FlowCtrl_Lid.stl` | **face down** | no supports; the display chamfer is on the bed, the bosses point up |
| `CYD_FlowCtrl_LightPipe.stl` | **flange down** | clear filament, **100 % infill**, slow — it's a 5 mm part |

Settings that matter: 0.2 mm layers (0.16 for a nicer chamfer), 3–4 perimeters so the lip and groove
are solid, PETG at your usual temperature, no supports on anything. Outer size 54.6 × 90.6 × 16.1 mm.

**Print the base first and try a USB-C cable in it.** That's the only fit that matters. If the plug
won't click home, sand the lead-in chamfer a little; if your printer runs fat and the lid is tight on
the base, a −0.1 mm horizontal-expansion (XY compensation) on the lid is the first knob to turn.

## 3 · Inserts

Do this **before** the board goes anywhere near the lid.

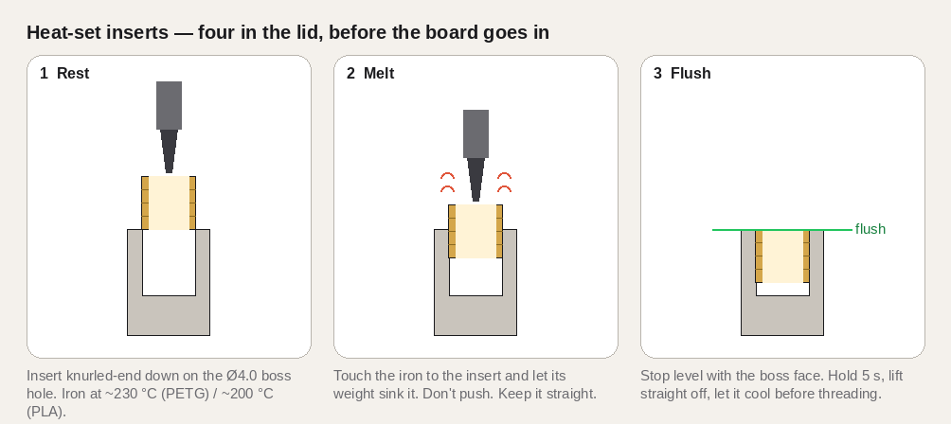
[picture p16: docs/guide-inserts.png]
Heat-set inserts


1. Set the iron to ~230 °C for PETG (~200 °C for PLA).
2. Rest an insert, knurled end down, on one of the four Ø4.0 mm holes in the lid bosses.
3. Touch the iron to the insert and let the iron's weight press it in — don't push. Keep it straight.
4. Stop when the insert is **flush** with the boss face. Hold 5 seconds, lift straight off.
5. Let it cool before threading anything in. Repeat ×4.

If one goes in crooked, reheat and nudge it; the boss has room. This is where the insert and the screw
sit in the finished stack — the screw comes up from the base, through the board, and gets about
3.9 mm of thread in the insert:

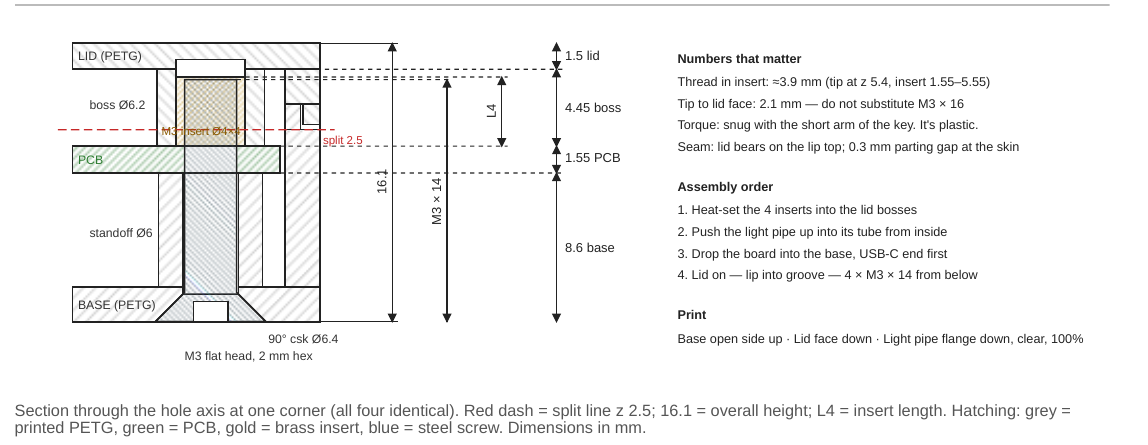
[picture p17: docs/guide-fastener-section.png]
Fastener section


## 4 · Flash the board on the bench

Easier out of the case: [`GETTING_STARTED.md`](GETTING_STARTED.md#1-set-up-once) has the two-line
flash. Confirm the screen comes up with "Pairing…" before you close anything up. If you hold BOOT while
plugging in, the port shows up on stubborn boards.

## 5 · Assemble

1. Push the **light pipe** up into its tube on the underside of the lid, flange against the ceiling.
2. Drop the **board** into the base, **USB-C end first**, so the port seats in the lower half of its
   opening. Screen up. The four corner holes line up over the standoffs.
3. **Lid on**: the tongue over the port goes into its slot, then the lip drops into the groove all the
   way round. It should seat with no force; if it doesn't, something's under it.
4. Flip it over and drive the **four M3 × 14 screws** from below, 2 mm hex, snug with the short arm
   of the key. It's plastic — stop when the head sits in the countersink.

Board in base
Underside

## 6 · Then

Pair it and set the one Wispr shortcut — [`GETTING_STARTED.md`](GETTING_STARTED.md). The light
sensor works through the pipe if you ever enable dimming; the RGB LED may show faintly through
lighter filament.

## What's covered on purpose
Micro-USB, the microSD slot, the RST/BOOT buttons and the JST headers are all inside. A flip-down SD
door is the obvious next feature if you need the card; the STEP files make that a small edit.

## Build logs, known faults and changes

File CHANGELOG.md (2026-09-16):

# Changelog

## v0.9.3 — 2026-09-16
- **Fix:** the Bluetooth link no longer drops every minute or two on macOS. The Mac moves a bonded
  keyboard to a high-latency link; the ESP32 could sleep past a channel-map update and get
  disconnected with `0x228`. The firmware now asks for a latency-0 link once encrypted and keeps it.
- Serial log (115200) is timestamped, prints connection-parameter changes and decodes disconnect
  reasons.
- Default Bluetooth TX power (the +9 dBm boost gained nothing on the CYD's PCB antenna).
- Prebuilt image: `release/flow-ctrl-v0.9.3-cyd2usb.bin`.

## v0.9 — 2026-09-16
- First public release: Dictate page (Hold to talk / Send / Hands-free), Transform page, printed
  housing v2, docs site and one-click flasher.

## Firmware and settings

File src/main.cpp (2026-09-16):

// Flow Ctrl — a Wispr Flow push-to-talk / hands-free button on the Cheap Yellow Display
// (ESP32-2432S028R). The board pairs with the Mac as a Bluetooth keyboard and sends
// Wispr's documented external-keyboard shortcuts:
//   HOLD TO TALK  →  the push-to-talk chord (default: Ctrl+Opt+T) held while your finger is down
//   HANDS-FREE    →  double-tap of the same chord (Wispr's "double-tap to lock" gesture);
//                    STOP taps the chord once more
//   SEND          →  Return (tap it once the pasted text has landed)
//   DISCARD (trash)  →  Esc
// Page 2 "TRANSFORM": Wispr Transforms on the current selection (table below): Prompt Engineer,
//   Drawing note, Client email — plus ⌘A select-all and ⌥O view-diff.
// Match PTT_MODS / PTT_KEY to Wispr Flow → Settings → General → Shortcuts → Push to talk.
// Landscape 320×240. LVGL 9 + TFT_eSPI + XPT2046 + NimBLE.

#include <Arduino.h>
#include <lvgl.h>
#include <TFT_eSPI.h>
#include <XPT2046_Touchscreen.h>
#include "theme.h"
#include "ble_kbd.h"

LV_IMAGE_DECLARE(ic_dictate);
LV_IMAGE_DECLARE(ic_transform);
LV_IMAGE_DECLARE(ic_handsfree);

// ---------------- hardware ----------------
#define SCREEN_W 320
#define SCREEN_H 240
#define XPT_IRQ 36
#define XPT_MOSI 32
#define XPT_MISO 39
#define XPT_CLK 25
#define XPT_CS 33
#define LED_R 4
#define LED_G 16
#define LED_B 17
#define BL_PIN 21
#define BL_CH 0
#ifndef PANEL_ROTATION
#define PANEL_ROTATION 1     // 1 = landscape (USB on the left), 3 = landscape flipped
#endif
#ifndef DIM_AFTER_MS
#define DIM_AFTER_MS 0       // 0 = always full brightness (the CYD is USB-powered, nothing to save).
#endif                       // Set e.g. -DDIM_AFTER_MS=45000 to dim after idle; it never turns off.
#define BL_FULL 255
#define BL_DIM 30
#ifndef BLE_NAME
#define BLE_NAME "Flow Ctrl"
#endif

// Chords Wispr Flow listens for (see docs.wisprflow.ai → Supported hotkeys)
#ifndef PTT_MODS
#define PTT_MODS  (MOD_CTRL | MOD_OPT)   // default push-to-talk chord: Ctrl + Opt + T
#endif
#ifndef PTT_KEY
#define PTT_KEY   KEY_T
#endif
#define DOUBLE_TAP_GAP_MS 120           // gap between the two taps that lock hands-free


// Wispr Transforms (Settings → Transforms). Act on the current selection. Add a row = a new button.
struct Transform { const char* name; const char* hint; uint8_t mods; uint8_t key; };
static const Transform XFORMS[] = {
  { "PROMPT ENGINEER", "Opt 2  ·  built in",      MOD_OPT, KEY_2 },
  { "DRAWING NOTE",    "Opt 3  ·  callouts", MOD_OPT, KEY_3 },
  { "CLIENT EMAIL",    "Opt 4  ·  client tone", MOD_OPT, KEY_4 },
};
#define N_XFORMS (sizeof(XFORMS) / sizeof(XFORMS[0]))

TFT_eSPI tft = TFT_eSPI(SCREEN_W, SCREEN_H);
SPIClass touchSpi = SPIClass(VSPI);
XPT2046_Touchscreen touch(XPT_CS, XPT_IRQ);
uint16_t tMinX = 300, tMaxX = 3800, tMinY = 300, tMaxY = 3800;

#define DRAW_BUF_SIZE (SCREEN_W * SCREEN_H / 10 * (LV_COLOR_DEPTH / 8))
static uint8_t* draw_buf;
static uint32_t lastTick = 0;

// ---------------- state ----------------
enum Cap { CAP_IDLE, CAP_PTT, CAP_HANDSFREE };
static Cap cap = CAP_IDLE;
static uint32_t capStart = 0;
static bool wasConnected = false;
static int blLevel = BL_FULL;

// ---------------- widgets ----------------
static lv_obj_t *dot, *lblTitle, *btnDiscard;
static lv_obj_t *pill, *lblStatus;
static lv_obj_t *btnPtt, *lblPtt, *micCap, *micCup, *micStem, *micBase;
static lv_obj_t *btnHf, *lblHf, *icoHf;
static lv_obj_t *btnSend, *lblSend, *lblSendSym;
static lv_obj_t *pageDictate, *pageXf, *segKnob, *tabDictate, *tabXf, *icoDictate, *icoXf;
static int knobX[2];
static int page = 0;
static lv_obj_t *toast, *toastTxt;
static uint32_t toastUntil = 0;
#define N_BARS 7
static lv_obj_t* bars[N_BARS];
static int barH[N_BARS];

// ---------------- display / touch glue ----------------
static void flush_cb(lv_display_t* disp, const lv_area_t* a, uint8_t* px) {
  uint32_t w = lv_area_get_width(a), h = lv_area_get_height(a);
  tft.startWrite();
  tft.setAddrWindow(a->x1, a->y1, w, h);
  tft.pushPixels((uint16_t*)px, w * h);
  tft.endWrite();
  lv_display_flush_ready(disp);
}

static void touch_read(lv_indev_t*, lv_indev_data_t* data) {
  if (touch.touched()) {
    TS_Point p = touch.getPoint();
    if (p.x < tMinX) tMinX = p.x; if (p.x > tMaxX) tMaxX = p.x;
    if (p.y < tMinY) tMinY = p.y; if (p.y > tMaxY) tMaxY = p.y;
    data->point.x = map(p.x, tMinX, tMaxX, 0, SCREEN_W - 1);
    data->point.y = map(p.y, tMinY, tMaxY, 0, SCREEN_H - 1);
    data->state = LV_INDEV_STATE_PRESSED;
#ifdef TOUCH_DEBUG
    Serial.printf("touch raw %d,%d -> %d,%d\n", p.x, p.y, data->point.x, data->point.y);
#endif
  } else {
    data->state = LV_INDEV_STATE_RELEASED;
  }
}

static void led(bool r, bool g, bool b) {  // active low
  digitalWrite(LED_R, r ? LOW : HIGH);
  digitalWrite(LED_G, g ? LOW : HIGH);
  digitalWrite(LED_B, b ? LOW : HIGH);
}
static void bl_set(int v) { ledcWrite(BL_CH, v); blLevel = v; }

// ---------------- helpers ----------------
static void show_toast(const char* s, uint32_t ms = 1400) {
  lv_label_set_text(toastTxt, s);
  lv_obj_remove_flag(toast, LV_OBJ_FLAG_HIDDEN);
  toastUntil = millis() + ms;
}

static lv_obj_t* box(lv_obj_t* parent, int x, int y, int w, int h, uint32_t color, int radius) {
  lv_obj_t* o = lv_obj_create(parent);
  lv_obj_remove_style_all(o);
  lv_obj_set_pos(o, x, y); lv_obj_set_size(o, w, h);
  lv_obj_set_style_bg_color(o, C(color), 0);
  lv_obj_set_style_bg_opa(o, LV_OPA_COVER, 0);
  lv_obj_set_style_radius(o, radius, 0);
  lv_obj_remove_flag(o, LV_OBJ_FLAG_SCROLLABLE);
  return o;
}
static lv_obj_t* label(lv_obj_t* parent, const char* s, const lv_font_t* f, uint32_t color) {
  lv_obj_t* l = lv_label_create(parent);
  lv_label_set_text(l, s);
  lv_obj_set_style_text_font(l, f, 0);
  lv_obj_set_style_text_color(l, C(color), 0);
  return l;
}

// ---------------- button row geometry (Dictate page) ----------------
// idle:       [HOLD TO TALK 112][SEND 112][HF 64]
// hands-free: HOLD slides off left, SEND slides to the left edge, STOP grows to fill the rest
#define ROW_X 12
#define ROW_Y 128
#define ROW_H (SCREEN_H - ROW_Y - 12)
#define W_PTT 112
#define W_SEND 112
#define W_HF 64
#define GAPB 4
#define X_SEND_IDLE (ROW_X + W_PTT + GAPB)
#define X_HF_IDLE (X_SEND_IDLE + W_SEND + GAPB)
#define X_HF_BIG (ROW_X + W_SEND + GAPB)
#define W_HF_BIG (SCREEN_W - ROW_X - X_HF_BIG)
#define ROW_ANIM_MS 220
static bool rowBig = false;

static void anim_x(lv_obj_t* o, int32_t to) {
  lv_anim_t a; lv_anim_init(&a); lv_anim_set_var(&a, o);
  lv_anim_set_values(&a, lv_obj_get_x(o), to); lv_anim_set_duration(&a, ROW_ANIM_MS);
  lv_anim_set_path_cb(&a, lv_anim_path_ease_out);
  lv_anim_set_exec_cb(&a, [](void* v, int32_t x) { lv_obj_set_x((lv_obj_t*)v, x); });
  lv_anim_start(&a);
}
static void anim_w(lv_obj_t* o, int32_t to) {
  lv_anim_t a; lv_anim_init(&a); lv_anim_set_var(&a, o);
  lv_anim_set_values(&a, lv_obj_get_width(o), to); lv_anim_set_duration(&a, ROW_ANIM_MS);
  lv_anim_set_path_cb(&a, lv_anim_path_ease_out);
  lv_anim_set_exec_cb(&a, [](void* v, int32_t w) { lv_obj_set_width((lv_obj_t*)v, w); });
  lv_anim_start(&a);
}
static void row_layout(bool big) {
  if (big == rowBig) return;
  rowBig = big;
  if (big) {
    anim_x(btnPtt, -W_PTT - 8);
    anim_x(btnSend, ROW_X);
    anim_x(btnHf, X_HF_BIG); anim_w(btnHf, W_HF_BIG);
  } else {
    anim_x(btnPtt, ROW_X);
    anim_x(btnSend, X_SEND_IDLE);
    anim_x(btnHf, X_HF_IDLE); anim_w(btnHf, W_HF);
  }
}

// ---------------- state → screen ----------------
static void render_state() {
  const bool on = BleKbd::connected();

  // connection dot + title
  lv_obj_set_style_bg_color(dot, C(on ? C_OK : C_WARN), 0);
  lv_label_set_text(lblTitle, on ? "Flow Ctrl" : "Pairing…");

  // status line under the pill
  static char buf[48];
  if (!on) {
    lv_label_set_text(lblStatus, "Add \"Flow Ctrl\" in Bluetooth settings");
  } else if (cap == CAP_PTT) {
    lv_label_set_text(lblStatus, "Listening — release to paste");
  } else if (cap == CAP_HANDSFREE) {
    uint32_t s = (millis() - capStart) / 1000;
    snprintf(buf, sizeof buf, "Hands-free  %lu:%02lu", (unsigned long)(s / 60), (unsigned long)(s % 60));
    lv_label_set_text(lblStatus, buf);
  } else {
    lv_label_set_text(lblStatus, "Ready");
  }

  // pill: rim glows while capturing
  lv_obj_set_style_border_color(pill, C(cap == CAP_HANDSFREE ? C_ACCENT : cap == CAP_PTT ? C_TEXT : C_BORDER), 0);

  // PTT button
  const bool pttDown = cap == CAP_PTT;
  lv_obj_set_style_bg_color(btnPtt, C(pttDown ? C_TEXT : C_SURFACE), 0);
  lv_obj_set_style_text_color(lblPtt, C(pttDown ? C_BG : C_TEXT), 0);
  lv_label_set_text(lblPtt, pttDown ? "LISTENING" : "HOLD TO TALK");
  const uint32_t micC = pttDown ? C_BG : C_TEXT;
  lv_obj_set_style_bg_color(micCap, C(micC), 0);
  lv_obj_set_style_border_color(micCup, C(micC), 0);
  lv_obj_set_style_bg_color(micStem, C(micC), 0);
  lv_obj_set_style_bg_color(micBase, C(micC), 0);

  // Hands-free button
  const bool hf = cap == CAP_HANDSFREE;
  lv_obj_set_style_bg_color(btnHf, C(hf ? C_ACCENT : C_SURFACE), 0);
  lv_obj_set_style_text_color(lblHf, C(hf ? C_ACCENT_TEXT : C_TEXT), 0);
  lv_obj_set_style_image_recolor(icoHf, C(hf ? C_ACCENT_TEXT : C_TEXT), 0);
  lv_label_set_text(lblHf, hf ? "STOP" : "");
  lv_obj_set_style_text_font(lblHf, hf ? F_TITLE : F_SMALL, 0);
  lv_obj_align(icoHf, LV_ALIGN_CENTER, 0, hf ? -18 : -10);
  lv_obj_align(lblHf, LV_ALIGN_CENTER, 0, hf ? 18 : 22);
  row_layout(hf);

  // disable buttons until paired
  if (on) { lv_obj_remove_state(btnPtt, LV_STATE_DISABLED); lv_obj_remove_state(btnHf, LV_STATE_DISABLED); lv_obj_remove_state(btnSend, LV_STATE_DISABLED); lv_obj_remove_state(btnDiscard, LV_STATE_DISABLED); }
  else    { lv_obj_add_state(btnPtt, LV_STATE_DISABLED);    lv_obj_add_state(btnHf, LV_STATE_DISABLED);    lv_obj_add_state(btnSend, LV_STATE_DISABLED);    lv_obj_add_state(btnDiscard, LV_STATE_DISABLED); }

#ifndef LED_QUIET
  if (!on) led(false, false, ((millis() / 500) % 4) == 0);   // slow blue blink while pairing
  else led(cap != CAP_IDLE, false, false);                   // red while capturing
#endif
}

// ---------------- waveform ----------------
static void wave_tick(lv_timer_t*) {
  const bool live = cap != CAP_IDLE;
  for (int i = 0; i < N_BARS; i++) {
    int target;
    if (live) {
      // centre-weighted random walk so it reads as speech, not noise
      int envelope = 10 + 18 * (N_BARS / 2 - abs(i - N_BARS / 2)) / (N_BARS / 2);
      target = 6 + (int)(esp_random() % (uint32_t)envelope);
    } else {
      target = 4;
    }
    barH[i] += (target - barH[i]) / 2;
    lv_obj_set_height(bars[i], barH[i]);
    lv_obj_set_style_bg_color(bars[i], C(live ? (cap == CAP_HANDSFREE ? C_ACCENT : C_WAVE_LIVE) : C_WAVE_IDLE), 0);
  }
}

// ---------------- key actions ----------------
static void ptt_start() {
  if (cap == CAP_HANDSFREE) { show_toast("Hands-free is on — tap STOP first"); return; }
  cap = CAP_PTT; capStart = millis();
  BleKbd::press(PTT_MODS);            // modifiers first, like a real keyboard
  delay(12);
  BleKbd::press(PTT_MODS, PTT_KEY);
  render_state();
}
static void ptt_end() {
  if (cap != CAP_PTT) return;
  BleKbd::releaseAll();
  cap = CAP_IDLE;
  render_state();
}
static void chord_tap() {
  // Real-keyboard order: modifiers first, then the key, then release.
  BleKbd::press(PTT_MODS);
  delay(12);
  BleKbd::press(PTT_MODS, PTT_KEY);
  delay(45);
  BleKbd::releaseAll();
}
static void hf_toggle() {
  if (cap == CAP_PTT) return;
  if (cap == CAP_HANDSFREE) {
    chord_tap();                         // one tap of the PTT chord ends the hands-free session
    cap = CAP_IDLE; show_toast("Pasted");
  } else {
    chord_tap(); delay(DOUBLE_TAP_GAP_MS); chord_tap();   // double-tap = Wispr's lock gesture
    cap = CAP_HANDSFREE; capStart = millis();
  }
  render_state();
}
static void send_return() {
  BleKbd::tap(0, KEY_ENTER);
  show_toast("Sent");
}
static void discard() {
  BleKbd::releaseAll();
  BleKbd::tap(0, KEY_ESC);
  cap = CAP_IDLE;
  show_toast("Discarded");
  render_state();
}

static void ptt_event(lv_event_t* e) {
  switch (lv_event_get_code(e)) {
    case LV_EVENT_PRESSED:     ptt_start(); break;
    case LV_EVENT_RELEASED:
    case LV_EVENT_PRESS_LOST:  ptt_end(); break;
    default: break;
  }
}
static void hf_event(lv_event_t* e) {
  const lv_event_code_t c = lv_event_get_code(e);
  if (c == LV_EVENT_SHORT_CLICKED) hf_toggle();
  else if (c == LV_EVENT_LONG_PRESSED) {   // resync without sending anything (e.g. you stopped it from the Mac)
    if (cap == CAP_HANDSFREE) { cap = CAP_IDLE; show_toast("Reset — nothing sent"); render_state(); }
  }
}
static void send_event(lv_event_t* e) {
  if (lv_event_get_code(e) == LV_EVENT_CLICKED) send_return();
}
static void discard_event(lv_event_t* e) {
  if (lv_event_get_code(e) == LV_EVENT_CLICKED) discard();
}

// ---------------- build ----------------
// ---------------- pages ----------------
static void set_page(int p) {
  if (cap == CAP_PTT) return;                      // never switch out from under a held chord
  page = p;
  if (p == 0) { lv_obj_remove_flag(pageDictate, LV_OBJ_FLAG_HIDDEN); lv_obj_add_flag(pageXf, LV_OBJ_FLAG_HIDDEN); }
  else        { lv_obj_add_flag(pageDictate, LV_OBJ_FLAG_HIDDEN);    lv_obj_remove_flag(pageXf, LV_OBJ_FLAG_HIDDEN); }
  lv_anim_t a; lv_anim_init(&a);
  lv_anim_set_var(&a, segKnob);
  lv_anim_set_values(&a, lv_obj_get_x(segKnob), knobX[p]);
  lv_anim_set_duration(&a, 180);
  lv_anim_set_path_cb(&a, lv_anim_path_ease_out);
  lv_anim_set_exec_cb(&a, [](void* o, int32_t v) { lv_obj_set_x((lv_obj_t*)o, v); });
  lv_anim_start(&a);
  lv_obj_set_style_image_recolor(icoDictate, C(p == 0 ? C_BG : C_TEXT_2), 0);
  lv_obj_set_style_image_recolor(icoXf,      C(p == 1 ? C_BG : C_TEXT_2), 0);
}
static void tab_event(lv_event_t* e) {
  if (lv_event_get_code(e) == LV_EVENT_CLICKED) set_page((int)(intptr_t)lv_event_get_user_data(e));
}
static void xf_event(lv_event_t* e) {
  if (lv_event_get_code(e) != LV_EVENT_CLICKED) return;
  const Transform* t = (const Transform*)lv_event_get_user_data(e);
  BleKbd::press(t->mods); delay(12); BleKbd::press(t->mods, t->key); delay(45); BleKbd::releaseAll();
  show_toast(t->name);
}
static void select_all_event(lv_event_t* e) {
  if (lv_event_get_code(e) != LV_EVENT_CLICKED) return;
  BleKbd::press(MOD_CMD); delay(12); BleKbd::press(MOD_CMD, KEY_A); delay(45); BleKbd::releaseAll();
  show_toast("Selected all");
}
static void diff_event(lv_event_t* e) {
  if (lv_event_get_code(e) != LV_EVENT_CLICKED) return;
  BleKbd::press(MOD_OPT); delay(12); BleKbd::press(MOD_OPT, KEY_O); delay(45); BleKbd::releaseAll();
  show_toast("View diff");
}

static lv_obj_t* make_button(lv_obj_t* parent, int x, int y, int w, int h) {
  lv_obj_t* b = lv_button_create(parent);
  lv_obj_remove_style_all(b);
  lv_obj_set_pos(b, x, y); lv_obj_set_size(b, w, h);
  lv_obj_set_style_bg_color(b, C(C_SURFACE), 0);
  lv_obj_set_style_bg_opa(b, LV_OPA_COVER, 0);
  lv_obj_set_style_bg_color(b, C(C_SURFACE_HI), LV_STATE_PRESSED);
  lv_obj_set_style_bg_opa(b, LV_OPA_40, LV_STATE_DISABLED);
  lv_obj_set_style_radius(b, R_BTN, 0);
  lv_obj_set_style_border_width(b, 1, 0);
  lv_obj_set_style_border_color(b, C(C_BORDER), 0);
  return b;
}
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
void loop() {
  lv_tick_inc(millis() - lastTick);
  lastTick = millis();
  lv_timer_handler();
  BleKbd::tick();
  delay(5);
}

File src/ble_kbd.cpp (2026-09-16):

#include "ble_kbd.h"
#include <NimBLEDevice.h>
#include <NimBLEHIDDevice.h>

// Standard boot-compatible keyboard report map, report ID 1:
// [modifiers][reserved][key1..key6]
static const uint8_t REPORT_MAP[] = {
  0x05, 0x01,        // Usage Page (Generic Desktop)
  0x09, 0x06,        // Usage (Keyboard)
  0xA1, 0x01,        // Collection (Application)
  0x85, 0x01,        //   Report ID (1)
  0x05, 0x07,        //   Usage Page (Key Codes)
  0x19, 0xE0,        //   Usage Minimum (224)
  0x29, 0xE7,        //   Usage Maximum (231)
  0x15, 0x00,        //   Logical Minimum (0)
  0x25, 0x01,        //   Logical Maximum (1)
  0x75, 0x01,        //   Report Size (1)
  0x95, 0x08,        //   Report Count (8)
  0x81, 0x02,        //   Input (Data, Variable, Absolute) — modifier byte
  0x95, 0x01,        //   Report Count (1)
  0x75, 0x08,        //   Report Size (8)
  0x81, 0x01,        //   Input (Constant) — reserved byte
  0x95, 0x06,        //   Report Count (6)
  0x75, 0x08,        //   Report Size (8)
  0x15, 0x00,        //   Logical Minimum (0)
  0x25, 0x65,        //   Logical Maximum (101)
  0x05, 0x07,        //   Usage Page (Key Codes)
  0x19, 0x00,        //   Usage Minimum (0)
  0x29, 0x65,        //   Usage Maximum (101)
  0x81, 0x00,        //   Input (Data, Array) — 6 key codes
  0x05, 0x08,        //   Usage Page (LEDs)
  0x19, 0x01, 0x29, 0x05, 0x95, 0x05, 0x75, 0x01,
  0x91, 0x02,        //   Output (Data, Variable, Absolute) — LED report
  0x95, 0x01, 0x75, 0x03,
  0x91, 0x01,        //   Output (Constant) — padding
  0xC0               // End Collection
};

static const uint32_t PARAM_REQ_DELAY_MS = 3000;   // settle time after encryption / after a Mac update
static const uint8_t  PARAM_REQ_MAX = 3;           // per connection, so we never ping-pong with the Mac
static NimBLEHIDDevice* hid = nullptr;
static NimBLECharacteristic* input = nullptr;
static volatile bool isConnected = false;

static uint32_t connectedAt = 0;
static uint32_t paramReqAt = 0;        // when to send our conn-param request (0 = nothing pending)
static uint8_t  paramReqCount = 0;     // requests sent on this connection (capped)
static bool     encrypted = false;
static uint16_t connHandle = 0;
static uint16_t curLatency = 0;
static uint16_t curTimeout10ms = 0;    // last reported supervision timeout, 10 ms units
static NimBLEServer* srv = nullptr;
static const char* reasonText(int r) {
  switch (r) {
    case 0x208: return "supervision timeout (link went quiet)";
    case 0x213: return "remote user terminated";
    case 0x216: return "local host terminated";
    case 0x23E: return "connection failed to establish";
    case 0x22E: return "LMP response timeout";
    case 0x228: return "instant passed (missed a channel-map/param update)";
    default: return "";
  }
}

static bool paramNeeded() { return curLatency > 2 || curTimeout10ms < 200; }

class ServerCB : public NimBLEServerCallbacks {
  void onConnect(NimBLEServer* server, NimBLEConnInfo& info) override {
    isConnected = true;
    connectedAt = millis();
    Serial.printf("[%8lu] [ble] connected %s  interval=%u latency=%u timeout=%ums\n", (unsigned long)millis(),
                  info.getAddress().toString().c_str(), info.getConnInterval(), info.getConnLatency(), info.getConnTimeout() * 10);
    // macOS opens every HID link with a 720 ms supervision timeout and then runs its own
    // parameter update. Asking for ours in the same instant collides with that (0x228 "instant
    // passed" and a drop), so the request is deferred to the main loop - see BleKbd::tick().
    srv = server;
    connHandle = info.getConnHandle();
    curLatency = info.getConnLatency();
    curTimeout10ms = info.getConnTimeout();
    encrypted = false;
    paramReqCount = 0;
    paramReqAt = 0;                                   // armed once the link is encrypted
  }
  void onDisconnect(NimBLEServer*, NimBLEConnInfo&, int reason) override {
    isConnected = false;
    paramReqAt = 0;
    encrypted = false;
    Serial.printf("[%8lu] [ble] disconnected 0x%03X %s after %lus - advertising\n", (unsigned long)millis(), reason,
                  reasonText(reason), (unsigned long)((millis() - connectedAt) / 1000));
    NimBLEDevice::startAdvertising();
  }
  void onAuthenticationComplete(NimBLEConnInfo& info) override {
    Serial.printf("[%8lu] [ble] auth complete, bonded=%d encrypted=%d\n", (unsigned long)millis(), info.isBonded(), info.isEncrypted());
    encrypted = info.isEncrypted();
    if (encrypted && !paramReqAt) paramReqAt = millis() + PARAM_REQ_DELAY_MS;
  }
  void onConnParamsUpdate(NimBLEConnInfo& info) override {
    curLatency = info.getConnLatency();
    curTimeout10ms = info.getConnTimeout();
    // macOS moves a bonded keyboard to latency 22: the board may then sleep through 22 events,
    // miss a channel-map instant and get dropped with 0x228. Ask again for latency 0.
    if (encrypted && !paramReqAt && paramNeeded()) paramReqAt = millis() + PARAM_REQ_DELAY_MS;
    Serial.printf("[%8lu] [ble] conn params now interval=%u latency=%u timeout=%ums\n", (unsigned long)millis(),
                  info.getConnInterval(), info.getConnLatency(), info.getConnTimeout() * 10);
  }
};

static void sendReport(uint8_t mods, uint8_t key) {
  if (!input || !isConnected) return;
  uint8_t r[8] = { mods, 0, key, 0, 0, 0, 0, 0 };
  input->setValue(r, sizeof(r));
  input->notify();
}

void BleKbd::begin(const char* deviceName) {
  NimBLEDevice::init(deviceName);
  // default TX power: +9 dBm gains nothing at desk range on the CYD PCB antenna
  NimBLEDevice::setSecurityAuth(true, false, true);   // bonding, no MITM, secure connections
  NimBLEDevice::setSecurityIOCap(BLE_HS_IO_NO_INPUT_OUTPUT);

  NimBLEServer* server = NimBLEDevice::createServer();
  server->setCallbacks(new ServerCB());
  server->advertiseOnDisconnect(true);

  hid = new NimBLEHIDDevice(server);
  hid->setManufacturer("WOODWERD");
  hid->setPnp(0x02, 0xE502, 0xA111, 0x0210);   // vendor source USB, generic ids
  hid->setHidInfo(0x00, 0x01);                  // country 0, flags: remote wake
  hid->setReportMap((uint8_t*)REPORT_MAP, sizeof(REPORT_MAP));
  input = hid->getInputReport(1);
  hid->getOutputReport(1);                      // keyboard LED report (ignored)
  hid->setBatteryLevel(100);
  hid->startServices();

  NimBLEAdvertising* adv = NimBLEDevice::getAdvertising();
  adv->setAppearance(HID_KEYBOARD);
  adv->addServiceUUID(hid->getHidService()->getUUID());
  adv->setName(deviceName);
  adv->enableScanResponse(true);
  adv->start();
  Serial.printf("[ble] advertising as \"%s\"\n", deviceName);
}

bool BleKbd::connected() { return isConnected; }
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

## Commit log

2026-09-16 Flow Ctrl v0.9: firmware, printed case, docs site
    Push-to-talk / hands-free button for Wispr Flow on the ESP32 Cheap Yellow
    Display. Firmware (PlatformIO, LVGL 9, NimBLE HID), split PETG case
    (STL/STEP + fastener spec), Getting Started and Build guides, MkDocs
    site with a one-click ESP Web Tools flash page.
    Claude-Session: https://claude.ai/code/session_015QGaYjJHwfhKYrhdMHbrBY
    [BOM.csv, CYD_FlowCtrl_Base.step, CYD_FlowCtrl_Base.stl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]
2026-09-16 Publishing notes: repo and docs-site URLs, Pages setting, day-to-day flow
    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
2026-09-16 Docs: housing v2 is the released design; v0.9 in daily use
    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
2026-09-16 v0.9.3: keep the BLE link out of latency so macOS stops dropping it
    macOS moves a bonded HID keyboard to interval 15 ms / latency 22. The ESP32
    then sleeps through up to 22 connection events, occasionally misses a
    channel-map instant and is disconnected with 0x228 - seen as the button
    falling back to "Pairing..." every minute or two.
    - ble_kbd: after encryption, request interval 12-24 / latency 0 / 6 s
    timeout from the main loop (BleKbd::tick), re-request if the Mac
    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
2026-09-16 Publishing notes: current version is v0.9.3
    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
2026-09-16 v0.9.4: Windows build, logo boot splash, About page
    - cyd2usb-win env (HOST_WIN): Alt/Ctrl labels on screen, Ctrl+A for
    Select all; push-to-talk arrives as Ctrl+Alt+T. Envs renamed
    cyd2usb-mac / cyd2usb-win, images -cyd2usb-mac.bin / -cyd2usb-win.bin,
    second install button + manifest-win.json on the Flash page
    - boot splash: WOODWERD badge (tools/make_logo.py -> src/assets/
    logo_woodwerd.c), version/build line and the programmed chord; painted
    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
2026-09-16 v0.9.5: pairing recovery, Forget pairing, clearer bench test
    - ble_kbd: after two encryption-step failures (0x205/0x206/0x23D) drop
    all bonds and flag needsRepair(); the status line then asks the user
    to remove and re-add the device. forgetPairing() for the About page
    button (two taps to confirm).
    - flash manifests: new_install_prompt_erase off, so a reflash keeps the
    bond
    - docs: pairing troubleshooting row, hands-free expectation, TESTING.md
    steps 2/6/8 rewritten from the first bench run's confusion
    - images: flow-ctrl-v0.9.5-cyd2usb-{mac,win}.bin
    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
2026-10-23 v0.9.6: Wispr-style screens, updates keep the pairing
    - Light theme matched to Wispr Flow; black talk bar with the waveform inside,
    full-width SEND, hands-free chip in the top row (tap the bar to stop),
    2x2 Transform page, About table, 12 px status line (Inter SemiBold 12).
    - Flash page writes bootloader / partitions / boot_app0 / app at their own
    offsets, so updates no longer blank NVS and wipe the Bluetooth pairing.
    tools/merge.sh also emits -update.bin (0x10000) and the pieces.
    - tools/sim: render the real firmware on a desktop; regenerates docs images.
    - README, Getting started, Flash, Firmware, Bench test updated for the new screens.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
2026-10-23 v0.9.7: light-sensor reading on the About page; release images
    - About page shows the live light-sensor value (with min/max since boot);
    groundwork for a backlight that follows the room. Hands-free row text updated.
    - release/: v0.9.7 full images (0x0, new boards), -update images (0x10000) and
    the bootloader / partitions / boot_app0 pieces the Flash page writes.
    v0.9.5 images retired (still attached to the v0.9.5 GitHub release).
    - Docs, manifests and screen-states point at v0.9.7. v0.9.6 was not released alone.
    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
2026-10-23 Docs: v0.9.7 in Getting started and Publishing; bench test covers updates and the light sensor
    Claude-Session: https://claude.ai/code/session_01JVki5LcRywJQKribFdpvas
2026-10-24 update case design callout
